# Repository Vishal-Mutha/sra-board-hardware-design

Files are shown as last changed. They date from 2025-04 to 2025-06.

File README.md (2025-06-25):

<!-- PROJECT LOGO -->
[][stars-url]
[][forks-url]
[][issues-url]
[][license-url]

<br/>

<p align="center">
  <a href="https://github.com/SRA-VJTI/sraboard-hardware-design">
    
  </a>

  <h3 align="center">SRA Development Board</h3>
  <p align="center">
    ESP32-based Development Board
    <br />
    <a href="https://github.com/SRA-VJTI/sra-board-hardware-design/tree/master/sra_dev_board_2025">KiCAD</a>
    ·
    <a href="https://github.com/Vishal-Mutha/sra-board-hardware-design/tree/master/gerbers">Gerber</a>
    ·
    <a href="https://github.com/Vishal-Mutha/sra-board-hardware-design/blob/master/documentation/images/board_images/front.png">Images</a>
    ·
    <a href="https://a360.co/3c1Rjyv">3D Model</a>
  </p>

# SRA Board 2025

The SRA board is a development board based on ESP32 with on-board peripherals like programmable LEDs, switches, sensor ports for Line Sensor Array and MPU-6050, protection circuit for over-current and reverse voltage and motor drivers.

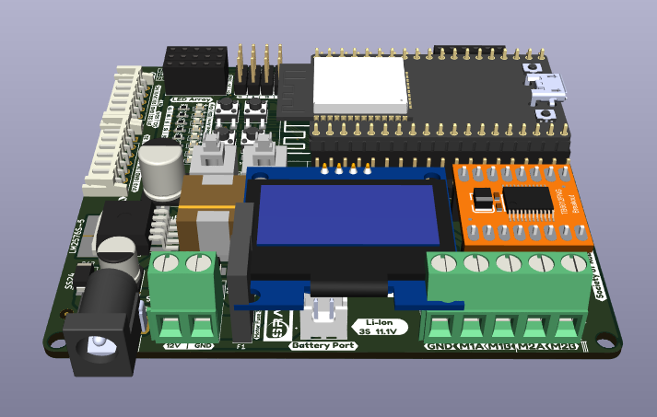
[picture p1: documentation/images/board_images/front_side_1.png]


## Table of Contents
- [SRA Board 2025](#sra-board-2025)
  - [Table of Contents](#table-of-contents)
  - [Board Images](#board-images)
  - [About the Project](#about-the-project)
  - [Getting Started with a Development Board](#getting-started-with-a-development-board)
  - [Notable problems in the previous SRA Boards](#notable-problems-in-the-previous-sra-boards)
  - [Notable problems in the current SRA Board](#notable-problems-in-the-current-sra-board)
  - [3D Models](#3d-models)
  - [Milestones](#milestones)
  - [Contributors](#contributors)
  - [Acknowledgements and Resources](#acknowledgements-and-resources)
  - [License](#license)

## Board Images
- **Frontside**
<p align="center">
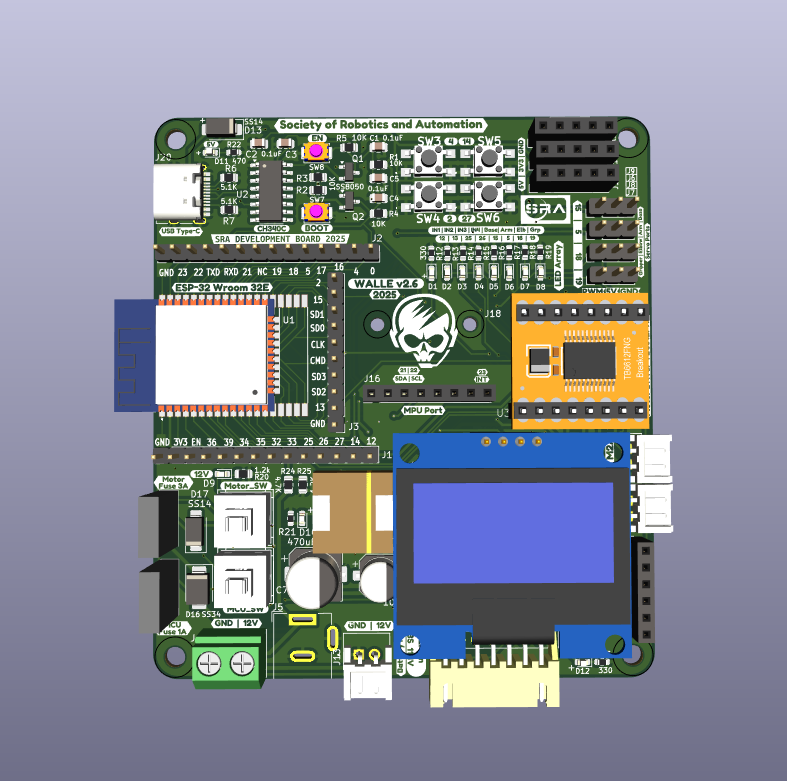
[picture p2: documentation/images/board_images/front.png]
  
</p>

- **Backside**
<p align="center">
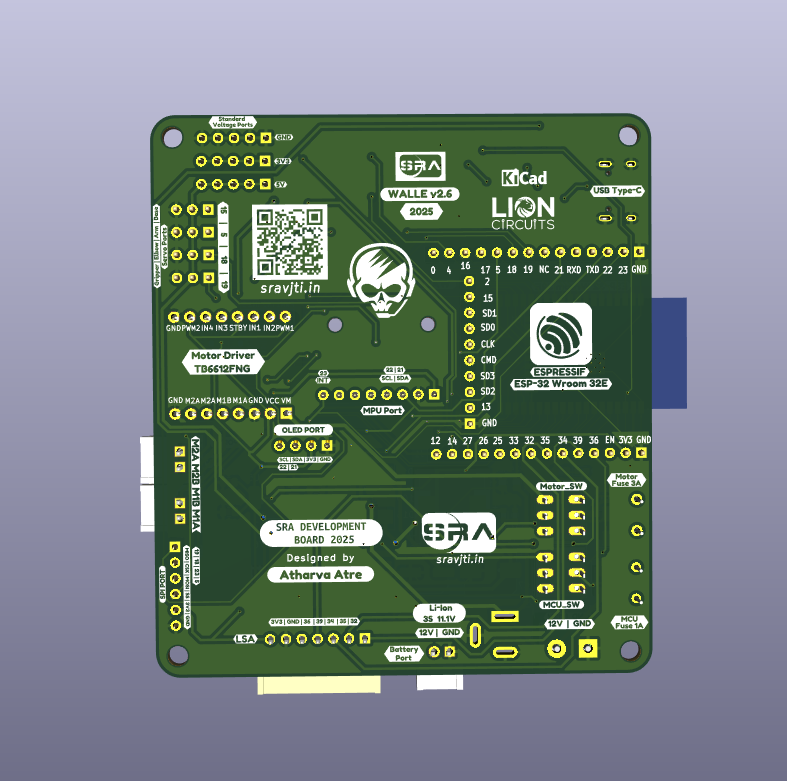
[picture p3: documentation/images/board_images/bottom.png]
  
</p>

## About the Project

- This development board is used for the [Wall-E](https://github.com/SRA-VJTI/Wall-E) and [MARIO](https://github.com/SRA-VJTI/MARIO) workshops conducted by [SRA](https://github.com/SRA-VJTI).
- Designed using KiCAD. The schematic and board files are [here](https://github.com/AtharvaAtre/SRA-Board/tree/master/sra_dev_board_2025).
- Resources for [previous work](https://github.com/SRA-VJTI/sra-board-hardware-design/tree/v2.2).  For more details of the SRA board 2020, checkout this [link](https://github.com/SRA-VJTI/sra-board-hardware-design/releases/tag/v2.4).
- The SRA board 2023 images can be found [here](https://github.com/SRA-VJTI/sra-board-hardware-design/tree/v2.4/documentation/images).
- Older versions of the board and miscellaneous designs can be found [here](https://github.com/SRA-VJTI/PCB-Schematics-and-Layouts).

## Getting Started with a Development Board

<p align="center">
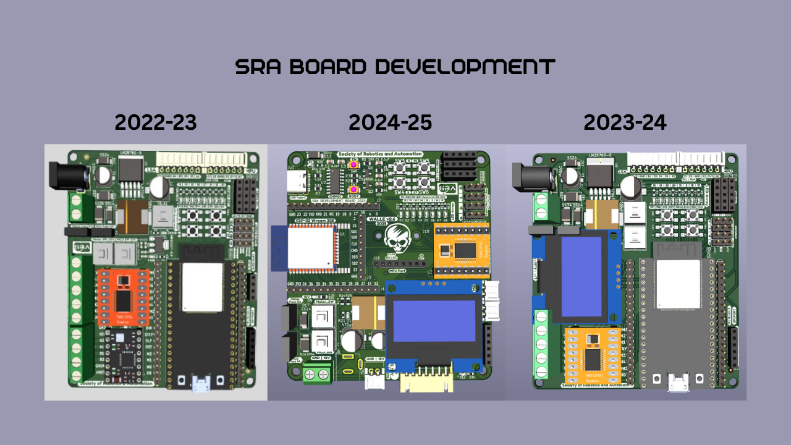
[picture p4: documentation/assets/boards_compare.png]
  
</p>

In general, every development board has the following basic features:

- ### Power Supply Unit
  - Microcontrollers (MCUs) usually run on 3.3V or 5V logic supply voltage while input to a development board is normally 12V for motor and driving/controlling peripheral devices.
  - So, in order to have a single input source, a *power* section which inter converts this 12V to standard levels like 5V & 3.3V for MCU and sensors is present.This is achieved using a step-down [buck regulator](https://www.youtube.com/watch?v=m8rK9gU30v4).
  - Buck Regulator IC [LM2576-S-5](./datasheets/lm2576_buck_regulator.pdf) is used for stepping down the voltage from 12V to 5V DC. This 5V is further regulated to 3.3V using LDO IC [AMS1117-3.3](./datasheets/ams1117_ldo.pdf).
  - The previous edition of the SRA board (2023) also used a similar buck regulator setup.
  - The older editions of the SRA board used the LM7805 linear voltage regulator, for stepping down from 12V to 5V; this powered the ESP32. Further, this 5V was converted to 3.3V using the LD33 linear voltage regulator, used by the sensor port.

- ### Motor Driver
    - Motors usually run on 12V and MCU output is generally 5V/3.3V. So, an external motor driver circuitry is required to control motors according to the MCU input.
    - The current and previous editions of SRA board use the [TB6612FNG](./datasheets/TB6612FNG_motor_driver.pdf) Motor Driver, which is a MOS-based H-Bridge motor driver.
    - The older editions of SRA Board used the L298N IC for motor-control, which is a BJT-based H-Bridge motor driver.

- ### Sensor Port
    - According to the external sensor types, usually development boards have onboard sensor ports where the sensors can be connected easily. [LSA - Line Sensor Array]() and [MPU- Motion Processing Unit]() have on-board connection ports.
    - The current edition uses easily available and efficient [JST XH connectors](https://en.wikipedia.org/wiki/JST_connector).
    - Previous versions used bulky [FRC connectors](https://www.sunrom.com/c/frc-idc-flat-cable-box-header#:~:text=FRC%20(Flat%20Ribon%20Cable)%20are,from%206%20to%2064%20pins.)

- ### Protection against [Reverse Voltage](https://www.google.com/url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)
    - The SRA Boards use diodes for reverse voltage protection in the power-line.
    - 12V Motor line and power regulated line have been separated with [SS34](./datasheets/ss34_3A_schottky_diode.pdf) and [SS24](./datasheets/ss24_2A_schottky_diode.pdf) schottky diodes respectively.

- ### Protection against [Over Current](https://www.baypower.com/blog/what-is-overcurrent-protection/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,of%20a%20piece%20of%20equipment.)
    - Earlier, for the overcurrent protection of MCU and motor driver circuit, bulky glass fuses of 300mA and 3A were used respectively. After breakdown, they used to be replaced.
    - In the recent versions of the board, these were replaced with compact, PTC Resettable Fuses.
    - On 12V line - [RXEF160](./datasheets/RUEF160_3,2A_trip_ptc_fuse.pdf) : 1.6A hold current; 3.2A trip current Fuse was used.
    - On 5V line - [RXEF160](./datasheets/RXEF050_1A_trip_ptc_fuse.pdf) : 0.5A hold current; 1A trip current Fuse was used.
- ### Programmable Switches and LEDs
    - Every development board should have some programmable switches and LEDs for testing, control and debugging purposes.
    - The current editions has an array of 8 programmable LEDs and switches.
    - The previous edition had a pair of programmable switches and programmable LEDs each.

- ### Power Switch
    - All versions have a power switch for the motor driver, using which power supply to the motor driver can be toggled. Similarly, there was a switch for the ESP32 MCU.

> Now that we covered basics of development boards, let us talk about the changes made in the new design. 

## Major Changes IN SRA Board Over the years from 2021-2025
| Feature  |  SRA Board 2021  | SRA Board 2022 | SRA Board 2023 | SRA Board 2024 | SRA Board 2025 |
|:----:|:---:| :-----: | :-----: | :-----: | :-----: |
|12V to 5V| LM2596 Buck Convertor | LM2596 Buck Converter | LM2576-S Buck Converter | LM2576-S Buck Converter | LM2576-S Buck Converter |
|Reverse Voltage Protection| P-MOSFET | Diodes | Diodes | Diodes | Diodes |
|Line Sensing Arrays (LSA)| Photodiodes| Photodiodes| IR Sensors| IR Sensors | IR Sensors |
|Number of LSA Sensors| 4| 4| 5| 5 | 5 |
|Motor Driver| TB6612FNG| TB6612FNG | TB6612FNG | TB6612FNG | TB6612FNG |
|Stepper Motor Driver| - | - | A4988 | - | - |
|No. of DC Motor Channels|4|4|2|2|2|
|No. of Stepper Motor Channels|0|0|1|1|0|
|No. of Switches|4|4|4|2|2|
|No. of LEDs|8|8|8|8|8|
|Over Current Protection| Bulky Glass Fuses | PTC Resettable Fuses | PTC Resettable Fuses| PTC Resettable Fuses | PTC Resettable Fuses |
|Sensor Port Connectors| JST (Japan Solderless Terminal) Connectors | JST (Japan Solderless Terminal) Connectors | JST Connectors | JST Connectors | JST Connectors |
|Component Type and Board Size| THT (Through Hole), Big | SMD(Surface Mount Device), Smaller | SMD(Surface Mount Device), Smaller| SMD(Surface Mount Device), Smaller | SMD(Surface Mount Device), Smaller |
|ESP32 Module| Not Integrated | Not Integrated | Not Integrated | Not Integrated | Mounted and Soldered to PCB |
|Flashing Port| Micro USB | Micro USB | Micro USB | Micro USB | Type-C |

- ### **Compatiblity of SRA Board with Battery [3- 3.3V 2500mAh Batteries](https://robu.in/product/bak-nmc-18650-2500mah-8c-lithium-ion-battery/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)**
    - This years SRA Board(2023-24) is compatible with batteries which have an external **[BMS(Battery Management System)](https://robu.in/product/3s-10a-12v-18650-lithium-battery-charger-board-protection-module/)**.
    - The BMS helps in maintaining an optimal voltage and disconnects itself when battery voltage drops below a significant voltage.
    - ALso the BMS helps in equal charging and discharging of 3 cells being used as a battery unit and thus helping in increasing the life/health of the battery.
    - ### **7805 (5V linear regulator) to [LM2576/96 Buck Convertor](https://www.youtube.com/watch?v=m8rK9gU30v4)**
    - The greater efficiency, output current and reliability of LM2576/96 were the reasons for this change.
    - The efficiency of LM2576 is up to 92% which is significantly better than 7805. The LM2576 can provide current up to 3A, so  the MARIO workshop manipulator can now be run using onboard regulator.
- ### **LD33 (3.3V) to [AMS1117](http://www.advanced-monolithic.com/pdf/ams1117.pdf)**:
    - The older editions used the LD33 IC to step down from 5V to 3.3V; several discussions resulted in the shift to more compact, reliable AMS1117-3.3(SOT-23) linear voltage regulator. (_AMS1117 is also used on-board on the ESP32-DevKitC V4 module_)

- ### **Reverse voltage protection: Diodes to P-MOSFET**
    - Diodes in series to the power line are inefficient as compare to a P-MOSFET. Dut to the usage of high-rated motors, it was difficult to manage the diode size and the current rating. (_As the current rating of diode increases, its size also increases._)So, the previous version uses the P-MOSFET instead of a diode, which is more efficient and can handle more current.
    - In the current edition, SMD diodes are used, hence rating and size is no longer an issue.

- ### **Component Type and Board Size**:
    - In the previous and older editions, THT or PTH(Plated through hole) components were used, which take up a lot of space and their size increases with increasing rating.
    - In the current edition, the component layout is changed,stepper motor driver is removed and the board is made battery compatible necessary changes for the same where done.
    - Current Board Dimensions: **81mm x 92.68mm**

- ### **L298N to [TB6612FNG](https://dronebotworkshop.com/tb6612fng-h-bridge/)**
    - L298N is a BJT-based H-bridge motor driver but it is less efficient as compared to the new MOS-based TB6612FNG.
    - The detailed comparison is shown below. As you can see the efficiency of TB6612FNG can reach up to 91-95% which is significantly higher than the 40-70% efficiency of L298N.
    - The only drawback of TB6612FNG is the less continuous current which is equal to 1.2A.
    
    <p align="center">
        
    </p>
- ### **Stepper Motor Driver Port ([A4988](https://www.tme.eu/Document/25459777e672c305e474897eef284f74/POLOLU-2128.pdf))**(Not present in 2023-24 and further)
    - In the Previous and older editions, there were two ports for TB6612FNG Motor Drivers but **it has been updated to one TB6612FNG and one A4988 Stepper Motor Driver in the current SRA Board (2023).** 
    - A4988 Stepper Motor Driver **a microstepping driver for controlling bipolar stepper motors** which has built-in translator for easy operation. This means that we can control the stepper motor with just 2 pins from our controller, or one for controlling the rotation direction and the other for controlling the steps.
    - The Driver provides five different step resolutions: full-step, haft-step, quarter-step, eight-step and sixteenth-step. Also, it has a potentiometer for adjusting the current output, over-temperature thermal shutdown and crossover-current protection.
    <p align="center">
        
    </p>

- ### **Moving back from the vintage Bar-graph LEDs to LED array and more switches**
    - The older edition used a pair of programmable switches and LEDs each.
    - Since the previous edition, the number of debuggable switches has been increased to 4.
    - The previous edition used an LED voltage bar-graph array of 10 LEDs which was very bulky.
    - In the current edition, 10 SMD LEDs arranged in an array out of which two are reserved for 5V and 3.3V voltage indication have been used.
    -  So there are 8 programmable LEDs on the board. These LEDs multiplexed with directional pins of the two motor drivers to save pins.
    -  Directional pins? >> Every motor driver channel has two directional pins IN1, IN2. If IN1 is high and IN2 is low then motors move in a clockwise direction and there are 4 channels on the board, so 4 * 2 = 8 directional pins are multiplexed with 8 programmable LEDs.
    -  With 8 LEDs in hand, debugging get easier. Some examples -
        1. According to the line sensor array (LSA) data, one can program 4 LEDs to turn on when the line sensor detects white  and turn off for black- line following debugging.
        2. If a motor is moving in a forward direction, the dedicated LEDs will be indicating IN1 is high and IN2 is low - motor control debugging.

## Notable problems in the previous SRA Boards
- ### **The Simultaneous Power Supply Issue**
    - ESP32 can be power using two ways - one via the USB port given on the ESP32 and two via providing a voltage on VIN pin.
    - In the SRA Board 2019, if simultaneous power (on both the above sources) was provided to the ESP32 then it won't work as there was no circuitry for handling such a condition.
    - The following disclaimer from the official ESP32 documentation made it essential to design some external circuit to handle this condition and accordingly pass only one signal to the ESP32 board.
    > *The power supply must be provided using one and only one of the above options.Otherwise, the board and/or the power supply source can be damaged.*
    - #### Solution
        - The solution for this issue was [Diode Auctioneering](http://doerry.org/norbert/papers/20190606-doerry-ashton-auctioneering-diodes.pdf).

        <p align="center">
            
        </p>

        - There is an inbuilt BAT760 diode on the USB line on ESP32. If different voltages are applied at Vusb and Vin, then the voltage with bigger magnitude will be given to LD1117 (LDO on ESP32); often the voltage will be the same on Vin and Vusb i.e 5V.
        - But, the usage of the SS14 (currently, 1N5417 in previous edition) diode on the Vin path, which has more **Vf** (forward voltage) than the BAT760, will create a voltage indifference and in a simultaneous power supply condition, USB will be selected as its voltage will be more than Vin.

## Notable problems in the previous SRA Board 
- ### **The High Frequency RF noise Issue**
    - Currently 300rpm rated BO motors were ultilised for application. These are brushed DC motors functioning currently on 12v working on PWM concept.
    - These BO motors drain a lot of current during operation. **90 - 100 mA** - during *normal operation*.
    But they drain about **600 - 700 mA** current - during *momentary or forced stalling*. Momentary stalling happens by itself.
    - For self balancing operation - the MCU communicates with MPU6050 for the current orientational readings and accordingly gives commands to the motor driver and thus the motors.
    - When this PWM goes over 50% duty cycle, the error in MPU readings become large and the motor rotate with full speed, thus not self-balancing the setup.
    - The following inspections were carried out os far so solve this issue.

    - #### Inspections
        - The static noise or low-frequecy noise generated by BO Motors was eliminated by soldering a 0.1uF ceramic capacitor across its terminals.
        - Initially, the longer length of the I2C line route + cable from the MPU6050 to the ESP32 was suspected to be the main culprt. However, the MPU was checked for I2C packet drop, which when observed under the a DSO, seemed pretty fine. While reading the Motion data, both the SDA and SCLK lines go high.
        - The dynamic high-frequency noise wasnt getting eliminated which is produced to the brush action of brushed DC motors. Finally adding [**ferrite beads**](https://www.youtube.com/watch?v=O39inZIscOI) across the motor terminals and using twisted cable pairs to connect it to the board lessened the RF noise to an extent.
        - Although, the above solution only facililated in lessening the frequency of system going into error. Also, the duty cycle was forced to be under 50% for opltimal application.

    - #### Possible Solutions
        - View this issue [#14](https://github.com/SRA-VJTI/sra-board-hardware-design/issues/14) for more details and advancements on the suggested solutions.
        - The above error didnot occur when L298 motor driver was used with the same setup.
        - Using N20 geared motors which draw relatively less current did not throw an error.
        - MPU can be taken upwards on the board itself rather than keeping it below near the motors so that noise can be minimized.        
        - Task is to figure out an economical alternative considering it to be a hardware issue.

## 3D Models

1. The complete 3D model (.step) file of [SRA Board 2025](./3d_models/sra_board_model/sra_dev_board_2025.step)
2. The 3D models of motor driver, LEDs, ESP32 etc.: [3d models of other components](./3d_models/)

<!-- Milestone -->
## Milestones

- [x] Designing of the prototype board
- [x] Modular testing of the circuit
- [x] Testing of prototype board
- [x] Final version
- [x] Making the board Battery Compatible
- [ ] Resolving high frequency noise by BO Motors ( TB6612FNG )

<!-- CONTRIBUTORS -->
## Contributors

- [Atharva Atre](https://github.com/AtharvaAtre): *Designer*
- [Dhairya Shah](https://github.com/dhairyashah1): *Mentor*
- [Mahesh Tupe](https://github.com/Asc91): *Mentor*
<!-- ACKNOWLEDGEMENTS AND REFERENCES -->
## Acknowledgements and Resources

- Previous Edition: [SRA Board 2024](https://github.com/SRA-VJTI/sra-board-hardware-design/releases/tag/v2.5)
- [KiCAD Tutorials](https://www.youtube.com/playlist?list=PL3bNyZYHcRSUhUXUt51W6nKvxx2ORvUQB)
- [README Template](https://github.com/roshanlam/ReadMeTemplate) by [roshanlam](https://github.com/roshanlam)

## License

- Distributed under the [MIT License](https://github.com/SRA-VJTI/sraboard-hardware-design/blob/master/LICENSE).

[forks-shield]:https://img.shields.io/github/forks/SRA-VJTI/sra-board-hardware-design
[forks-url]: https://github.com/SRA-VJTI/sra-board-hardware-design/network/members

[stars-shield]: https://img.shields.io/github/stars/SRA-VJTI/sra-board-hardware-design
[stars-url]: https://github.com/SRA-VJTI/sra-board-hardware-design/stargazers

[issues-shield]: https://img.shields.io/github/issues/SRA-VJTI/sra-board-hardware-design
[issues-url]: https://github.com/SRA-VJTI/sra-board-hardware-design/issues

[license-shield]: https://img.shields.io/github/license/SRA-VJTI/sra-board-hardware-design
[license-url]: https://github.com/SRA-VJTI/sra-board-hardware-design/blob/master/LICENSE

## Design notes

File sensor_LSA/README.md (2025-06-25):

## LSA - Line Sensor Array

### Table of Contents
* [Overview](#overview)
* [Features](#features)
* [Components of LSA](#components-of-lsa)
* [Function of Components](#function-of-components)
	* [LED](#function-of-components)
	* [PhotoDiode](#function-of-components)
	* [IC LM324](#function-of-components)
	* [Resistors](#function-of-components)
* [Connections](#connections)
* [Working Principle](#working-principle)
* [Appplications](#applications)
* [Scope of Improvement](#scope-of-improvement)

### Overview
- The Line Sensor Array(LSA) is used to detect the white/black lined surface and it sends this data to the microcontroller ESP-32. Analyzing and processing the data received by the microcontroller ESP-32, the purpose of line following is achieved.

- Physical PCB
<p align="center">
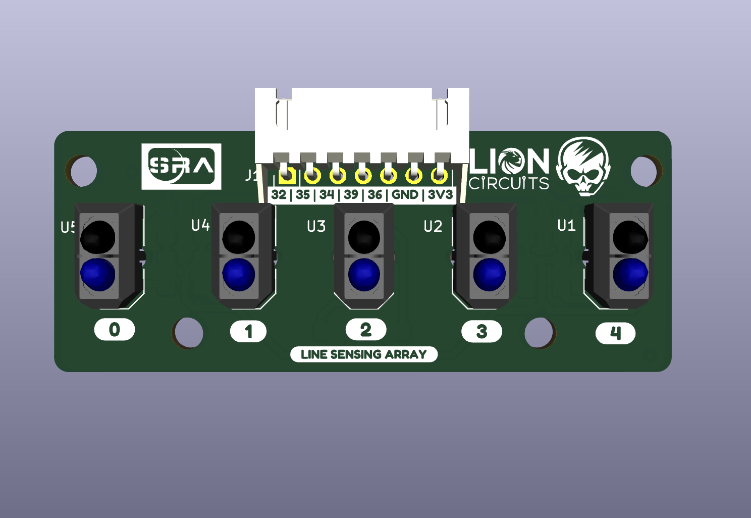
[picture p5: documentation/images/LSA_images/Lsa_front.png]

</p>

- PCB Backside
<p align="center">
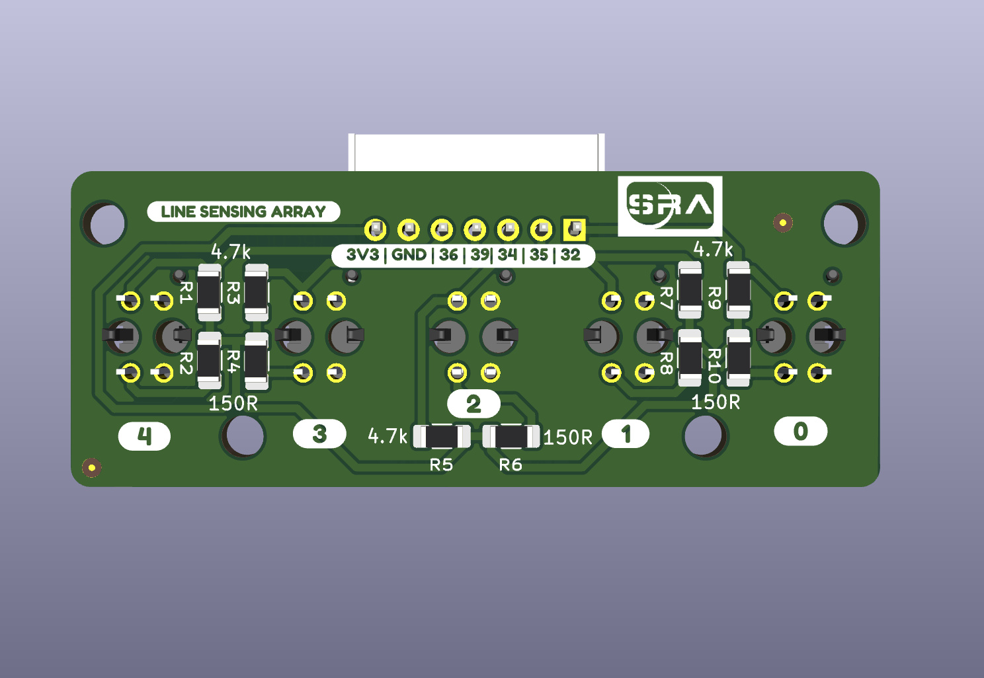
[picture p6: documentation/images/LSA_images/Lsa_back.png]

</p>

### Features
* Components used are readily available.
* Easy connections for output signals.
* Compact enough to fit into any project.
* Distinguished trace widths for Signal and Power Routes.

### Components of LSA
| Component | Description | Quantity |
| --- | --- | --- |
| Infrared Emmitter | Emits infrared light |  5 |
| PhotoTransistor  | Absorbs light |  5 |
| Resistors | Limit Current |  10 |
|JST Connector | Connect PCB with other circuits|1|

### Function of Components
- **Infrared Emmitter**
	- The specific Infrared Emmitter emit infrared light which is incident on the surface and some of it is absorbed by the surface. The voltage source for the Infrared Emmitter to emit is VCC.

- **PhotoTransistor**
	- Based upon the reflectivity coefficient of the surface( generally less than 1), the remaining light reflected from the surface is captured by the Photodiodes. Infrared Emmitter and complimentary phototransistor are used to efficiently detect the surface (white/black line). The amount of light received is directly proportional to the current generated by it. More the light, more the current, more the reading.

- **Resistors**
	- Now to limit the current and thus to protect the LEDs, PhotoDiodes current limiting resistors are used.

### Connections
To connect LSA with the SRA Board, connect the JST connector in the following way:
<p align="center">
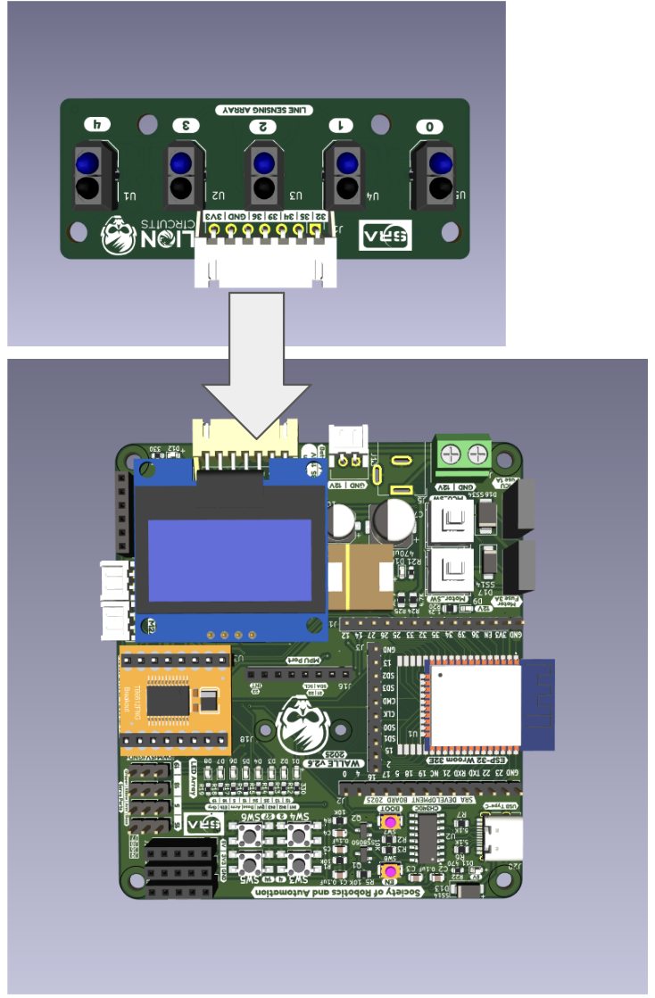
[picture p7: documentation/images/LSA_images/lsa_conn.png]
 
</p>

### Working Principle
- LSA works on the principle of reflectivity of light for different types of surfaces.
	- Black Surface -> HIGH absorptivity -> LESS reflectivity
	- White Surface -> LOW absorptivity -> HIGH reflectivity
- Demonstration
<p align="center">
 
</p>

### Applications
* Obstacle detection on a clear path.
* Line Following.
* Distinguish Colours on a path.

### Scope of Improvement
- LSA sometimes provides slightly inaccurate readings due to external light and conditions due to non uniformity of the colour of the path. Therefore, LSA has low accuracy. Hence LSA should be kept close to the ground.
- As of now only white and black surfaces are being mapped. Given accurate sensors and proper mapping we can map LSA for any range of RGB colours.

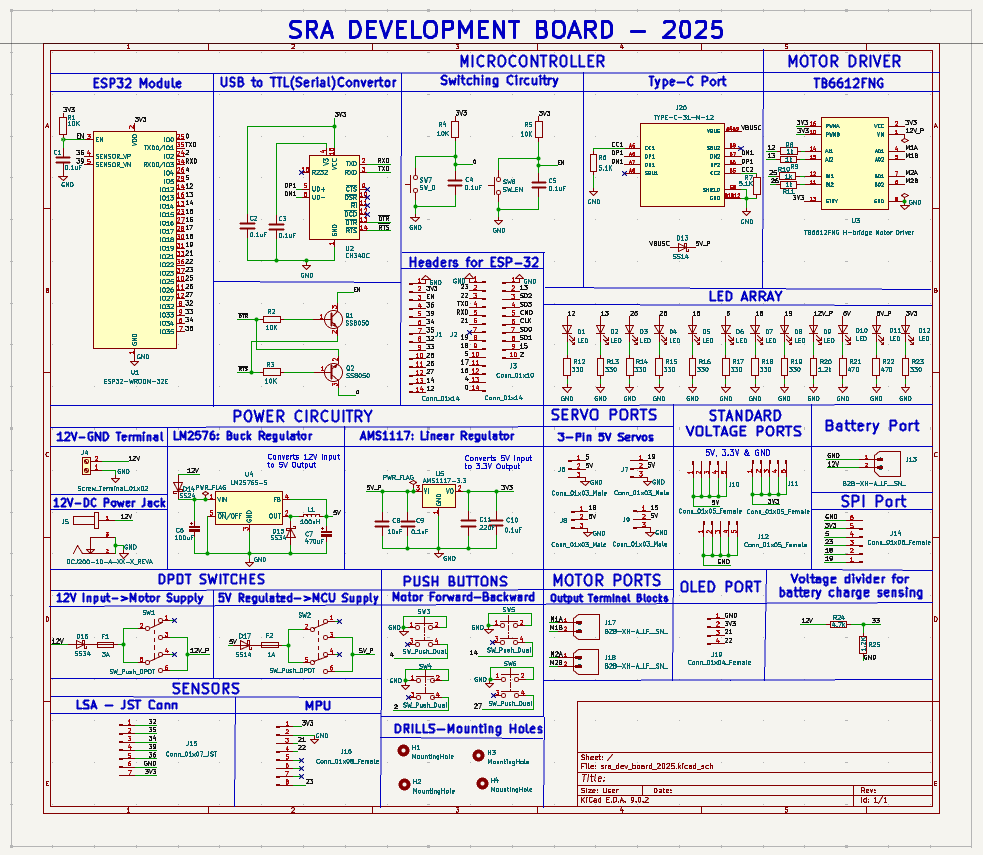
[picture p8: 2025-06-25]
documentation/images/board_images/schematic.png

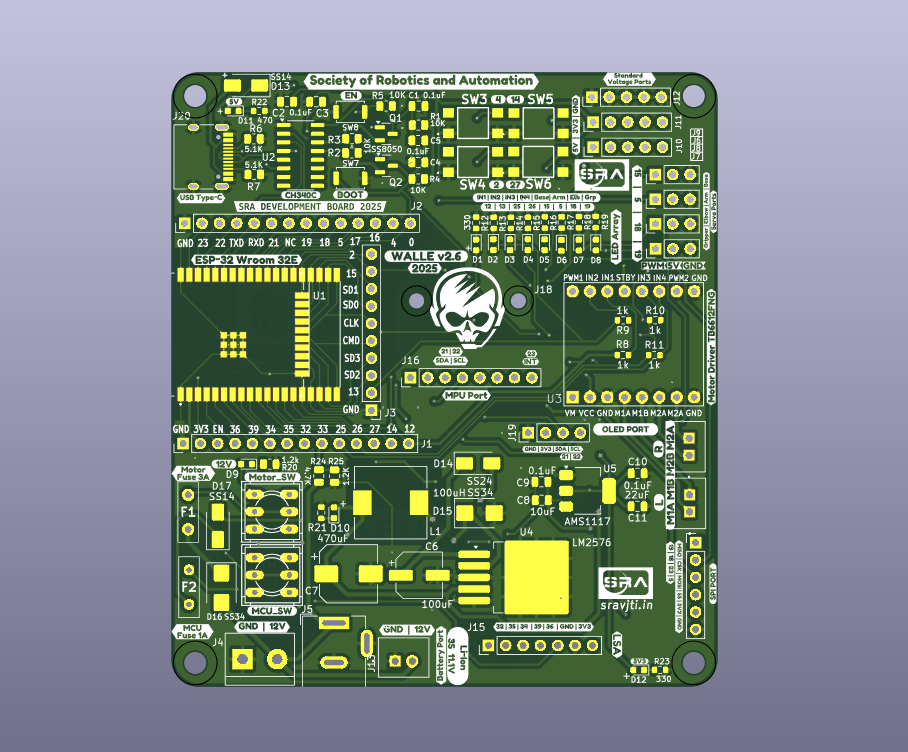
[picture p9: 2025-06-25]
documentation/images/board_images/front_silkscreen.png

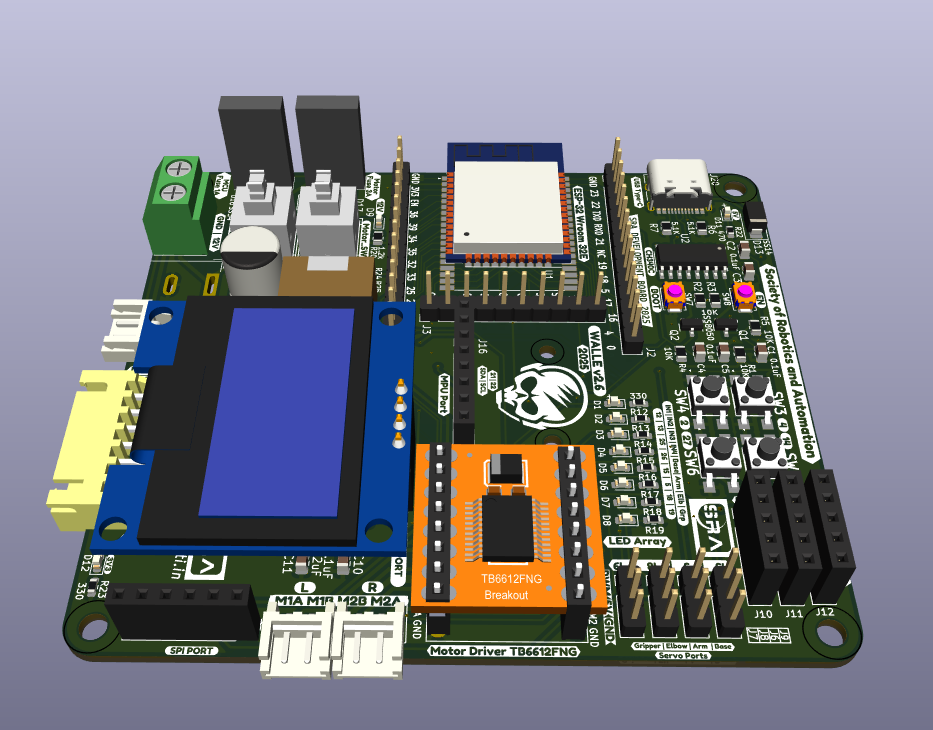
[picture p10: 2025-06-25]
documentation/images/board_images/front_view_1.png

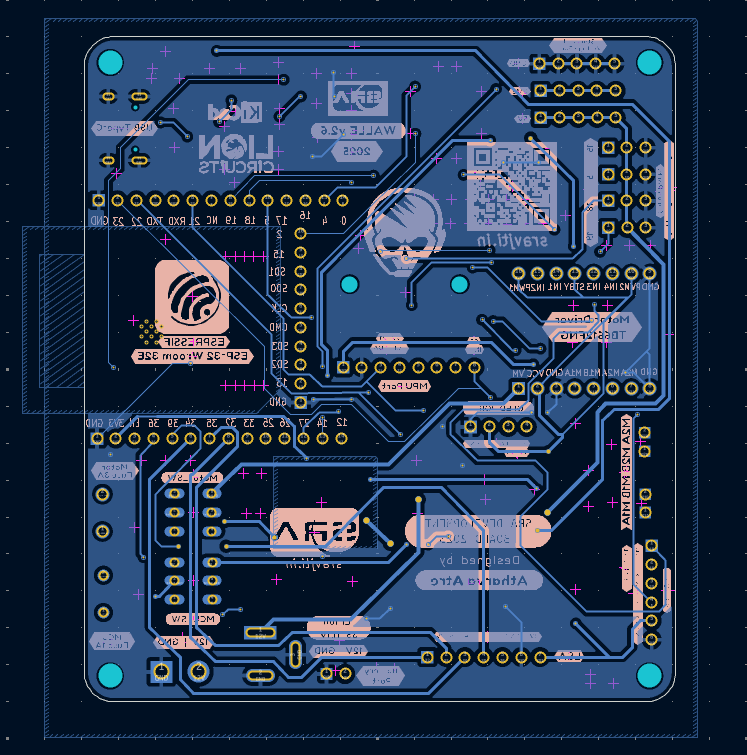
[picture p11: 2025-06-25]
documentation/images/board_images/bcu.png

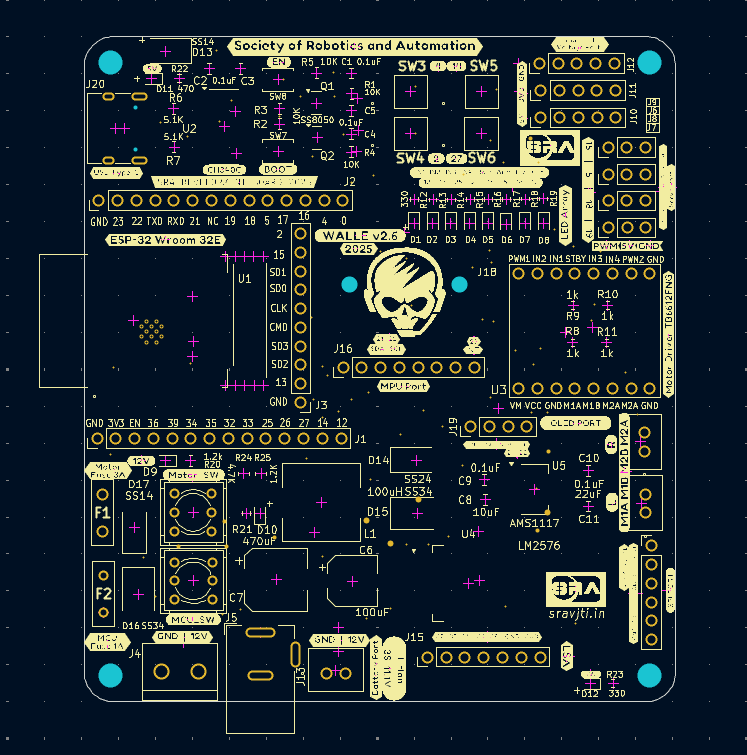
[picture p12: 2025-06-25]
documentation/images/board_images/front_silk_layer.png

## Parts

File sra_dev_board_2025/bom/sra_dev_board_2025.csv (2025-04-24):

Sr No. | Reference | Value | Footprint | Qty | Description
1 | C1,C2,C3,C4,C5,C9,C10 | 0.1uF | Capacitor_SMD:C_0805_2012Metric | 7 | Capacitor
2 | C6 | 100uF | Capacitor_SMD:CP_Elec_6.3x7.7 | 1 | Capacitor
3 | C7 | 470uF | Capacitor_SMD:CP_Elec_8x10 | 1 | Capacitor
4 | C8 | 10uF | Capacitor_SMD:C_0805_2012Metric | 1 | Capacitor
5 | C11 | 22uF | Capacitor_SMD:C_0805_2012Metric | 1 | Capacitor
6 | D1,D2,D3,D4,D5,D6,D7,D8,D9,D10,D11,D12 | LED | LED_SMD:LED_0603_1608Metric | 12 | LED
7 | D13,D17 | SS14 | Diode_SMD:D_SMA | 2 | Schotky Diode
8 | D14 | SS24 | Diode_SMD:D_SMA | 1 | Schotky Diode
9 | D15,D16 | SS34 | Diode_SMD:D_SMB | 2 | Schotky Diode
10 | F1 | 3A | PTC Fuse:3A RUEF160 | 1 | Fuse
11 | F2 | 1A | PTC Fuse:3A RUEF160 | 1 | Fuse
12 | J1,J2 | Conn_01x14 | Connector_PinHeader_2.54mm:PinHeader_1x14_P2.54mm_Vertical | 2 | Male Header
13 | J3 | Conn_01x10 | Connector_PinHeader_2.54mm:PinHeader_1x10_P2.54mm_Vertical | 1 | Male Header
14 | J4 | Screw_Terminal_01x02 | TerminalBlock:TerminalBlock_bornier-2_P5.08mm | 1 | 2 Pin Screw Terminal
15 | J5 | DCJ200-10-A-XX-X_REVA | Connector_BarrelJack:BarrelJack_Wuerth_6941xx301002 | 1 | DC Jack
16 | J6,J7,J8,J9 | Conn_01x03_Male | Connector_PinHeader_2.54mm:PinHeader_1x03_P2.54mm_Vertical | 4 | Male Header
17 | J10,J11,J12 | Conn_01x05_Female | Connector_PinHeader_2.54mm:PinHeader_1x05_P2.54mm_Vertical | 3 | Female Header
18 | J13,J17,J18 | B2B-XH-A_LF__SN_ | JST Connector:2 Pin JST Connector | 3 | JST Connector 2 Pin
19 | J14 | Conn_01x06_Female | Connector_PinHeader_2.54mm:PinHeader_1x06_P2.54mm_Vertical | 1 | Female Header
20 | J15 | Conn_01x07_JST | Connector_PinHeader_2.54mm:PinHeader_1x07_P2.54mm_Vertical | 1 | JST Connector 7 Pin
21 | J16 | Conn_01x08_Female | Connector_PinHeader_2.54mm:PinHeader_1x08_P2.54mm_Vertical | 1 | Female Header
22 | J19 | Conn_01x04_Female | Connector_PinHeader_2.54mm:PinHeader_1x04_P2.54mm_Vertical | 1 | Female Header
23 | J20 | TYPE-C-31-M-12 | Connector_USB:USB_C_Receptacle_HRO_TYPE-C-31-M-12 | 1 | Type-C Connector
24 | L1 | 100uH | Inductor_SMD:L_10.4x10.4_H4.8 | 1 | Inductor
25 | Q1,Q2 | SS8050 | Package_TO_SOT_SMD:SOT-23 | 2 | Trannsistor
26 | R1,R2,R3,R4,R5 | 10K | Resistor_SMD:R_0805_2012Metric | 5 | Resistor
27 | R6,R7 | 5.1K | Resistor_SMD:R_0805_2012Metric | 2 | Resistor
28 | R8,R9,R10,R11 | 1k | Resistor_SMD:R_0603_1608Metric | 4 | Resistor
29 | R12,R13,R14,R15,R16,R17,R18,R19,R23 | 330 | Resistor_SMD:R_0603_1608Metric | 9 | Resistor
30 | R20,R25 | 1.2k | Resistor_SMD:R_0805_2012Metric | 2 | Resistor
31 | R21,R22 | 470 | Resistor_SMD:R_0603_1608Metric | 2 | Resistor
32 | R24 | 4.7k | Resistor_SMD:R_0805_2012Metric | 1 | Resistor
33 | SW1,SW2 | SW_Push_DPDT | Switches:dpdt_sw_2x03_tht | 2 | 6 Pin DPDT Switch
34 | SW3,SW4,SW5,SW6 | SW_Push_Dual | Switches:spst_tactile_sw_2x02_smd | 4 | 4 Pin Tactile Switch
35 | SW7,SW8 | SW_0,SW_EN | Button_Switch_SMD:SW_Push_SPST_NO_Alps_SKRK | 2 | 2 Pin Tactile Switch
36 | U1 | ESP32-WROOM-32E | ESP-32:ESP32-WROOM-32E__4MB_HIGH_TEMP_ | 1 | ESP32 Wroom 32E
37 | U2 | CH340C | Package_SO:SOIC-16_3.9x9.9mm_P1.27mm | 1 | USB TTL Convertor
38 | U3 | TB6612FNG H-bridge Motor Driver | Motor Drivers:TB6612FNG | 1 | 2 1x8 Female Headers
39 | U4 | LM2576S-5 | Package_TO_SOT_SMD:TO-263-5_TabPin3 | 1 | Buck Convertor
40 | U5 | AMS1117-3.3 | Package_TO_SOT_SMD:SOT-223-3_TabPin2 | 1 | Linear Voltage regulator

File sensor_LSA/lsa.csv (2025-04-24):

Source: | /home/chinmay/Desktop/sra-board-hardware-design/sensors_2023/lsa/lsa/lsa.kicad_sch
Date: | Sun 11 Dec 2022 02:22:51 AM IST
Tool: | Eeschema 6.0.9-8da3e8f707~117~ubuntu22.04.1
Generator: | /usr/share/kicad/plugins/bom_csv_grouped_by_value_with_fp.py
Component Count: | 16
Ref | Qnty | Value | Cmp name | Footprint | Description | Vendor
J1, | 1 | Conn_01x07_Male | Conn_01x07_Male | Connector_PinHeader_2.54mm:PinHeader_1x07_P2.54mm_Vertical | Generic connector, single row, 01x07, script generated (kicad-library-utils/schlib/autogen/connector/)
R1, R3, R5, R7, R9, | 5 | 4.7k | R | Resistor_SMD:R_1206_3216Metric_Pad1.30x1.75mm_HandSolder | Resistor
R2, R4, R6, R8, R10, | 5 | 150R | R | Resistor_SMD:R_1206_3216Metric_Pad1.30x1.75mm_HandSolder | Resistor
U1, U2, U3, U4, U5, | 5 | TCRT5000 | TCRT5000 | TCRT5000:OPTO_TCRT5000

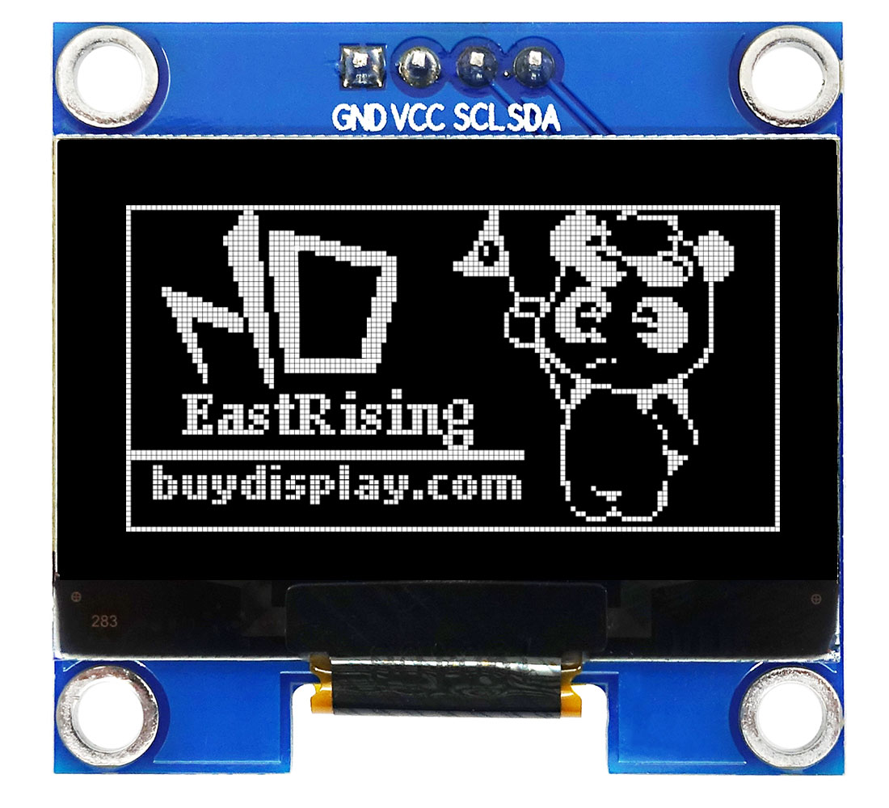
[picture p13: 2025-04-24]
sra_dev_board_2025/component_libraries/oled/I2C White 1.3 inch OLED Display Module 128x64 Arduino,Raspberry Pi.jpg

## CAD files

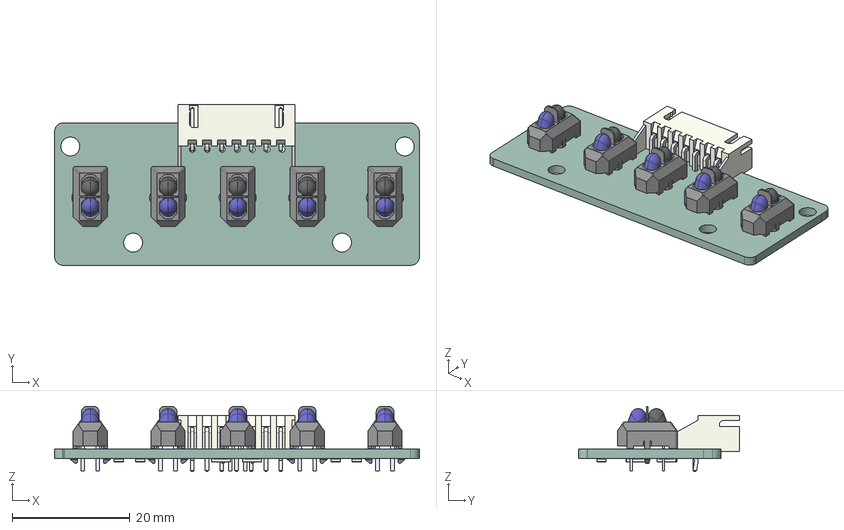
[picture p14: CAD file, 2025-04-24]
3d_models/lsa_model/lsa-2025.step
61.9 x 27.3 x 11.1 mm
JST_S7B_XH_A_1
TCRT5000 x 5
R_1206_3216Metric x 10
_autosave-lsa_PCB

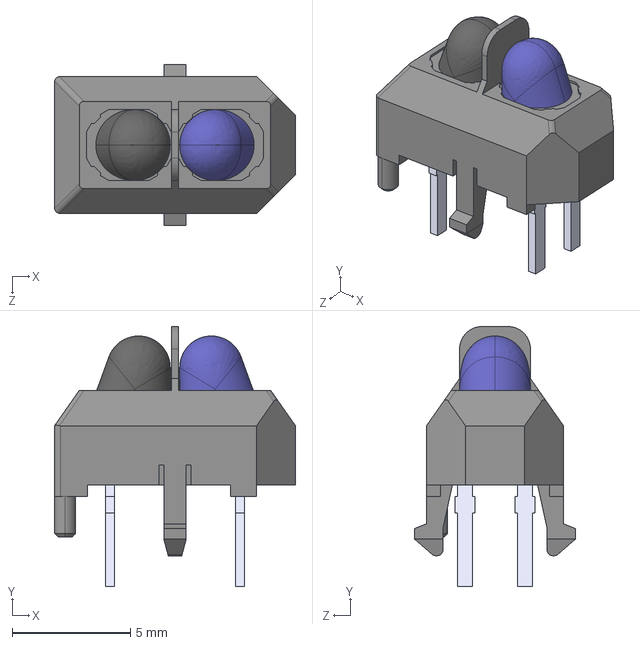
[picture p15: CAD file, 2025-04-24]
sensor_LSA/component_libraries/TCRT5000/TCRT5000.step
10.2 x 11.0 x 6.80 mm

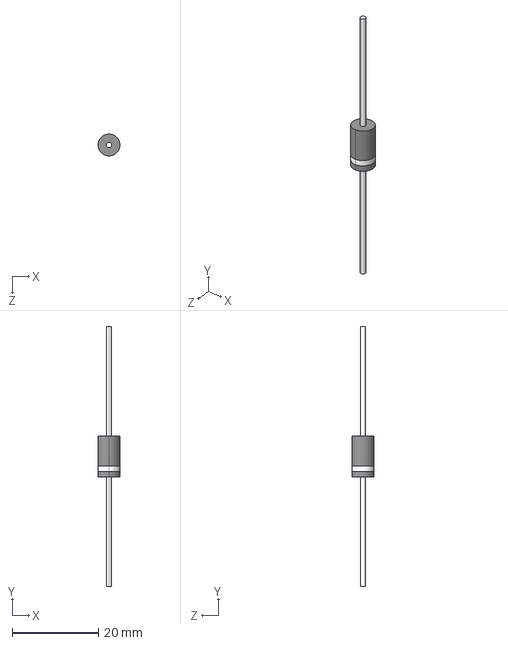
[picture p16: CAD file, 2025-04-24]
sra_dev_board_2025/component_libraries/diode/1N5822/1N5822.STEP
5.08 x 60.3 x 5.08 mm

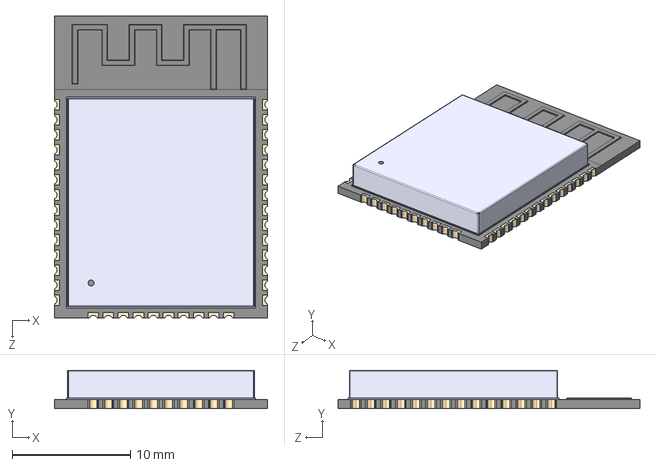
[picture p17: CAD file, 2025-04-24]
sra_dev_board_2025/component_libraries/ESP32-WROOM/ESP32-WROOM-32E__4MB_HIGH_TEMP_.step
18.0 x 3.25 x 25.5 mm

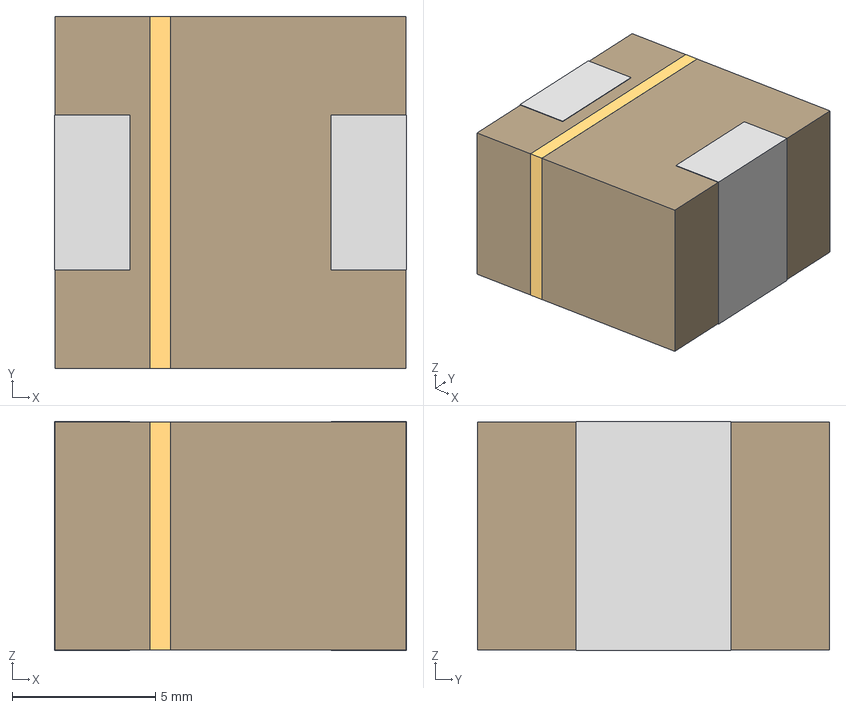
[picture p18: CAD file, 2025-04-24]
sra_dev_board_2025/component_libraries/inductor/CDRH127_inductor_smd.step
12.3 x 12.3 x 8.00 mm

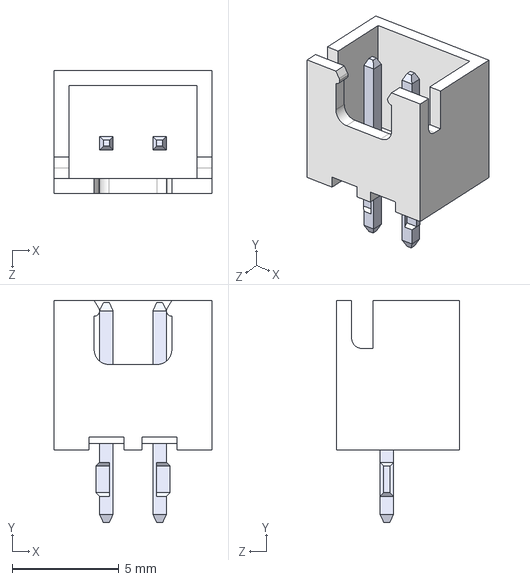
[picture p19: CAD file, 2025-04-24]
sra_dev_board_2025/component_libraries/JST Connector/2 Pin JST_Power&Motors/B2B-XH-A_LF__SN_.step
7.40 x 10.4 x 5.75 mm

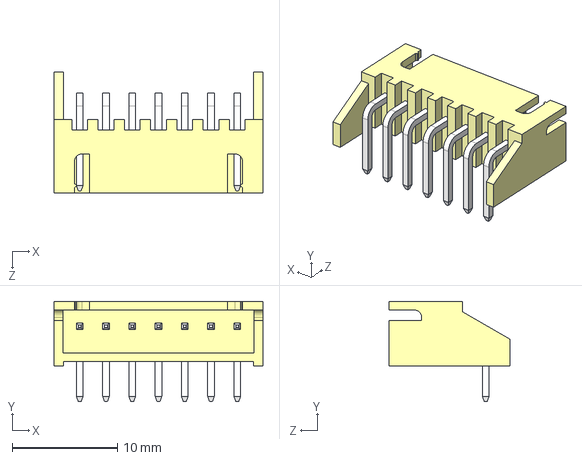
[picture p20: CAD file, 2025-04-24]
sra_dev_board_2025/component_libraries/JST Connector/7 Pin JST_LSA/S7B-XH-A_LF__SN_.step
19.9 x 9.55 x 11.5 mm

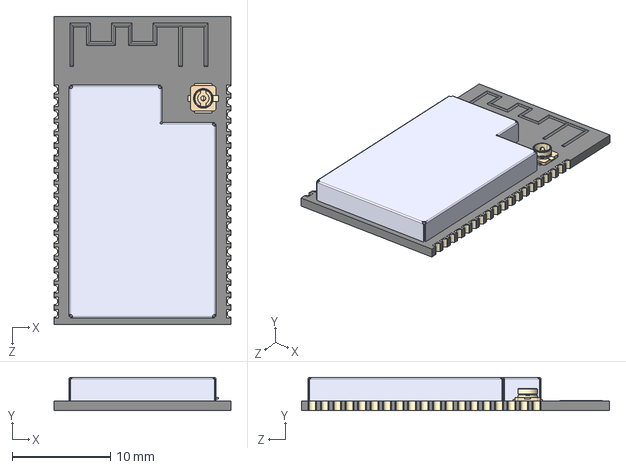
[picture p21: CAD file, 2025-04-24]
sra_dev_board_2025/component_libraries/MCU_ESP32/ESP32-WROVER.step
18.0 x 3.40 x 31.4 mm

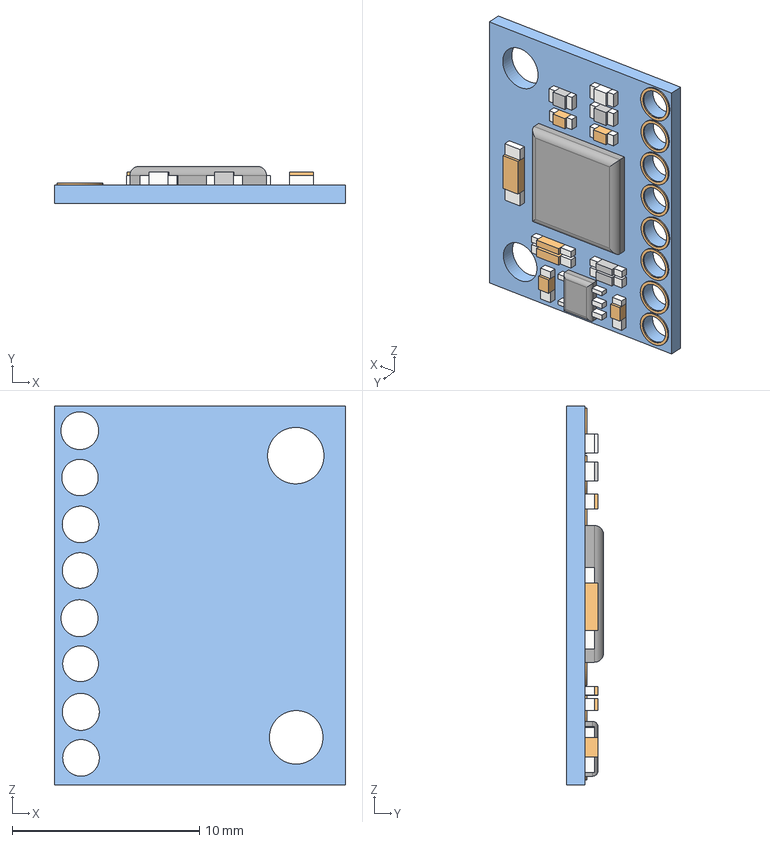
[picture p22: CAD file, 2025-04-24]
sra_dev_board_2025/component_libraries/MPU/MPU6050/MPU6050 v2.step
15.6 x 2.00 x 20.3 mm

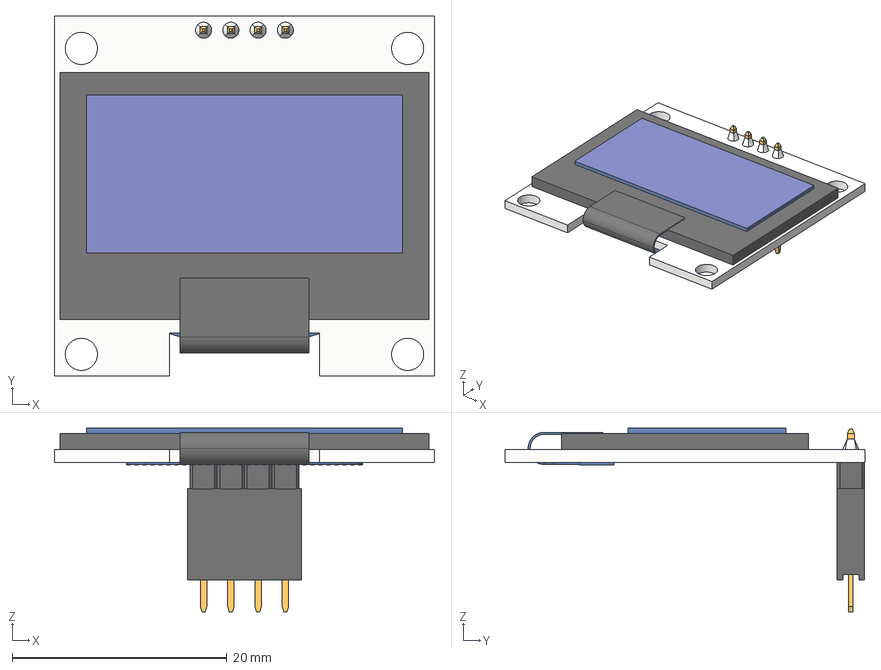
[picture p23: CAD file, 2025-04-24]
sra_dev_board_2025/component_libraries/oled/PCB v8.step
35.4 x 33.5 x 17.1 mm
Board
PIN HEADER MALE 2.54MM P4
LCD
FLEX FILM
4 lü Lehim
PIN HEADER FAMALE 2.54MM P4

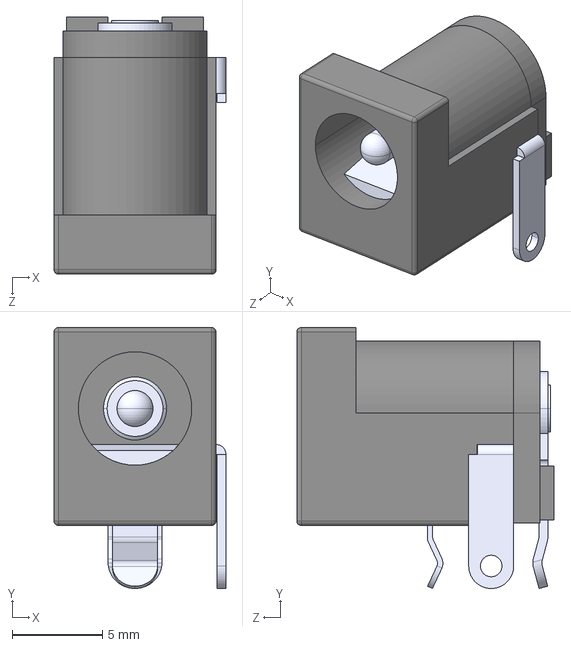
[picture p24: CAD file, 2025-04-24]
sra_dev_board_2025/component_libraries/power_jack/dc_power_jack.step
9.55 x 14.5 x 14.3 mm

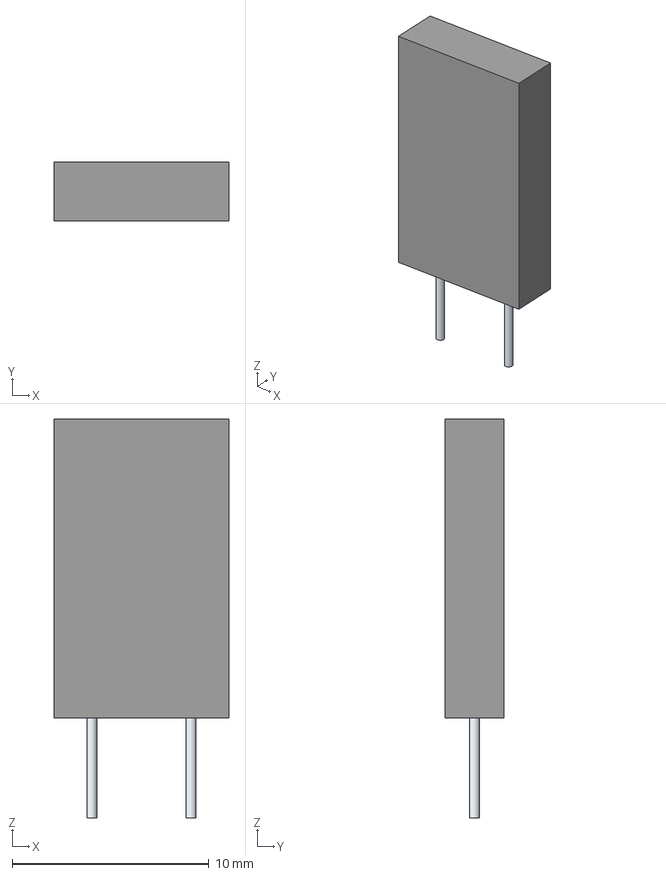
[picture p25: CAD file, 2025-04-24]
sra_dev_board_2025/component_libraries/ptc_fuse/RUEF150_3,2A_trip/RUEF160.stp
8.90 x 3.00 x 20.3 mm
Leads

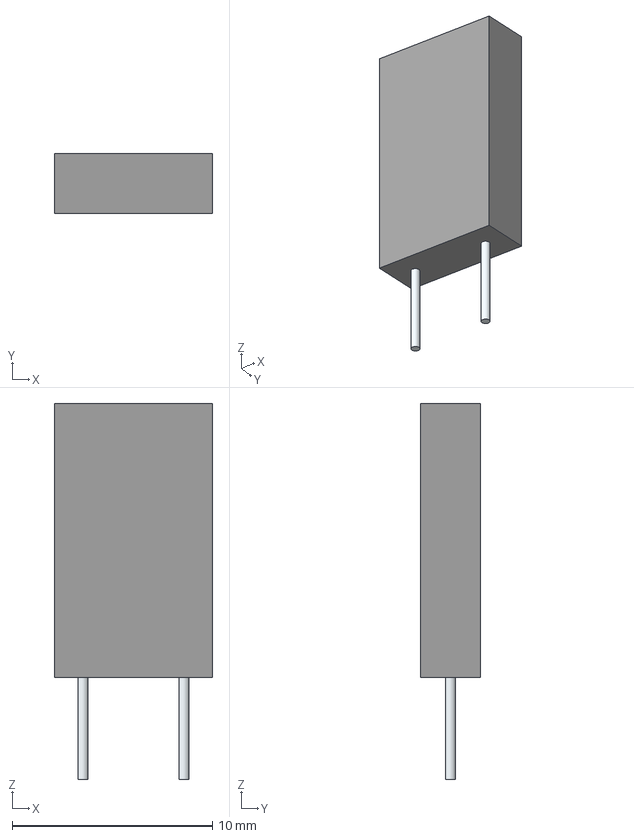
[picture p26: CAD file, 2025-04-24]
sra_dev_board_2025/component_libraries/ptc_fuse/RXEF050_1A_trip/RXEF050.stp
7.90 x 3.00 x 18.8 mm
Leads x 2

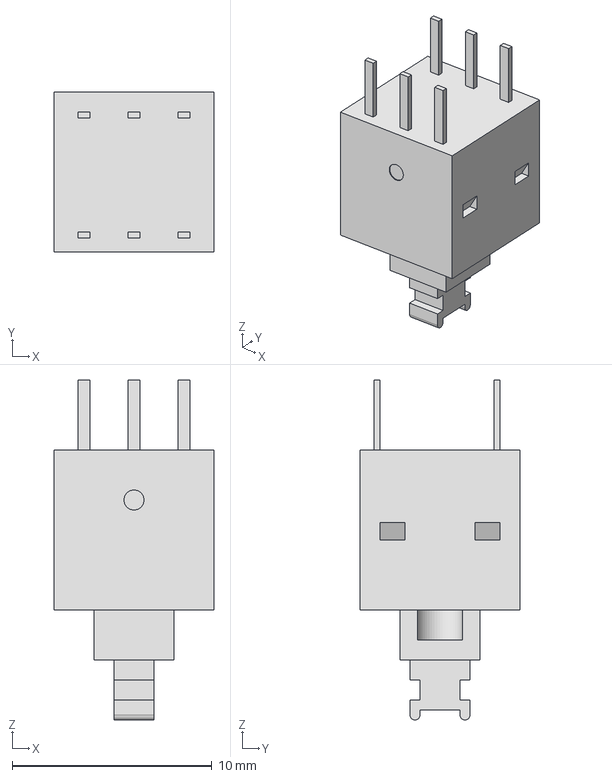
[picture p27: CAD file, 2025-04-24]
sra_dev_board_2025/component_libraries/switches/dpdt_tht/dpdt_sw_2x03_tht.STEP
8.00 x 8.00 x 17.0 mm

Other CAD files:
sra_dev_board_2025/component_libraries/switches/Esp-32 Switch/skrkaee010.stp
sra_dev_board_2025/component_libraries/switches/tactile_smd/spst_tactile_sw_2x02_smd.stp
sra_dev_board_2025/component_libraries/terminal_block/12V_1x02_tht.step
sra_dev_board_2025/component_libraries/inductor/CDRH104R_inductor_smd.stp
sra_dev_board_2025/component_libraries/oled/ER-OLEDM013-1-SPI-I2C.x_t
sra_dev_board_2025/component_libraries/oled/PCB v8.f3d
sra_dev_board_2025/component_libraries/ptc_fuse/RUEF150_3,2A_trip/RUEF160.stl
sra_dev_board_2025/component_libraries/ptc_fuse/RXEF050_1A_trip/RXEF050.stl

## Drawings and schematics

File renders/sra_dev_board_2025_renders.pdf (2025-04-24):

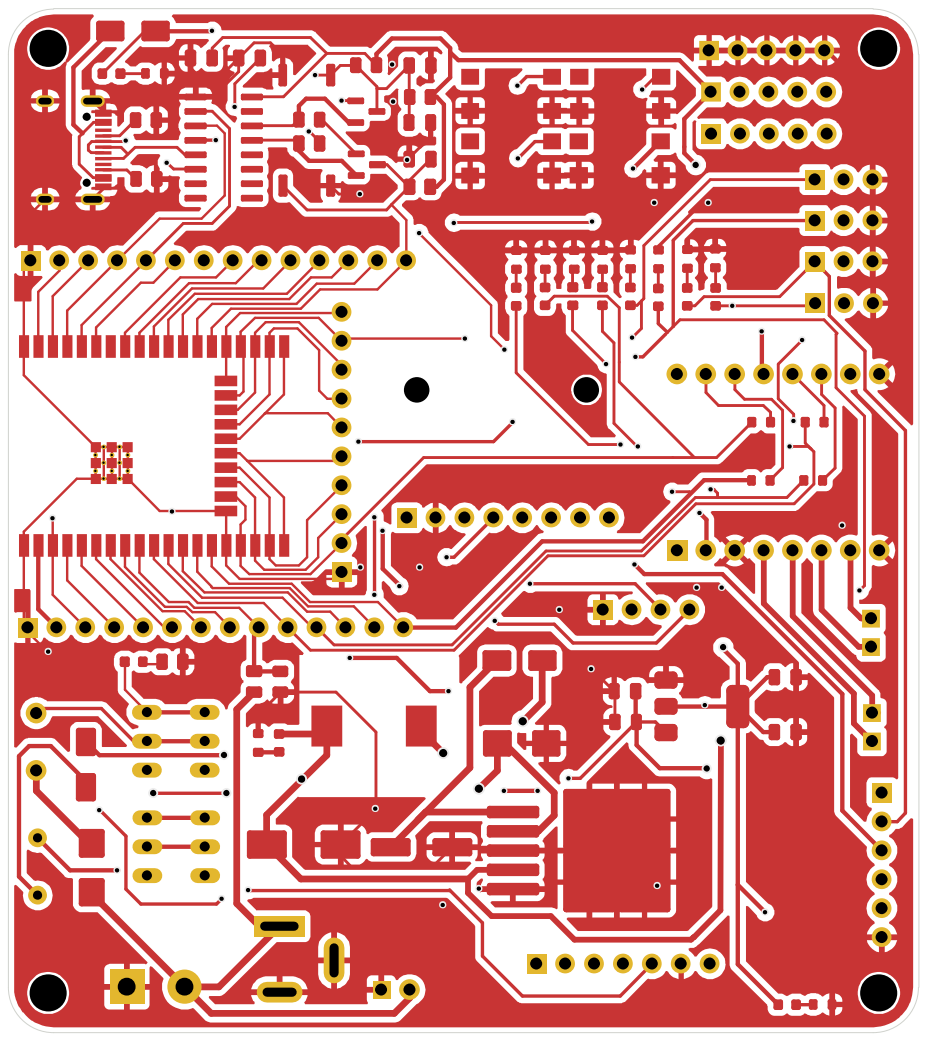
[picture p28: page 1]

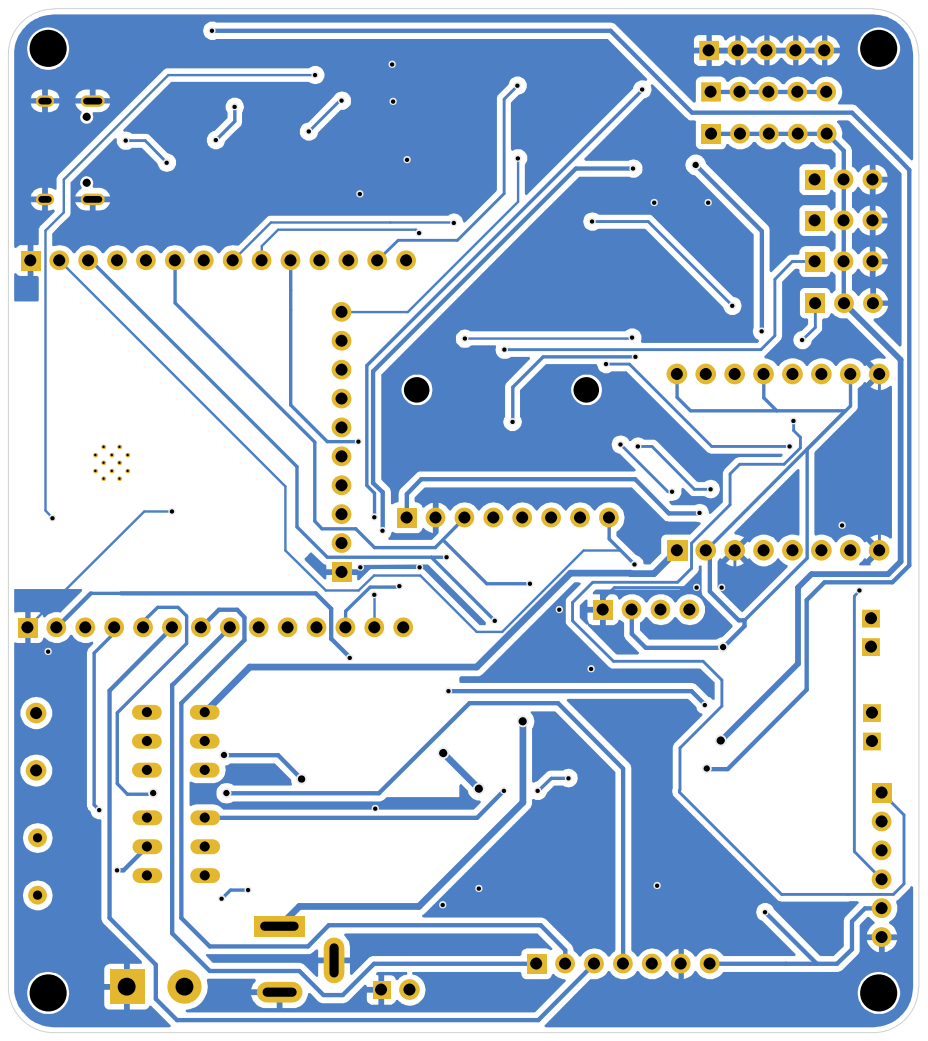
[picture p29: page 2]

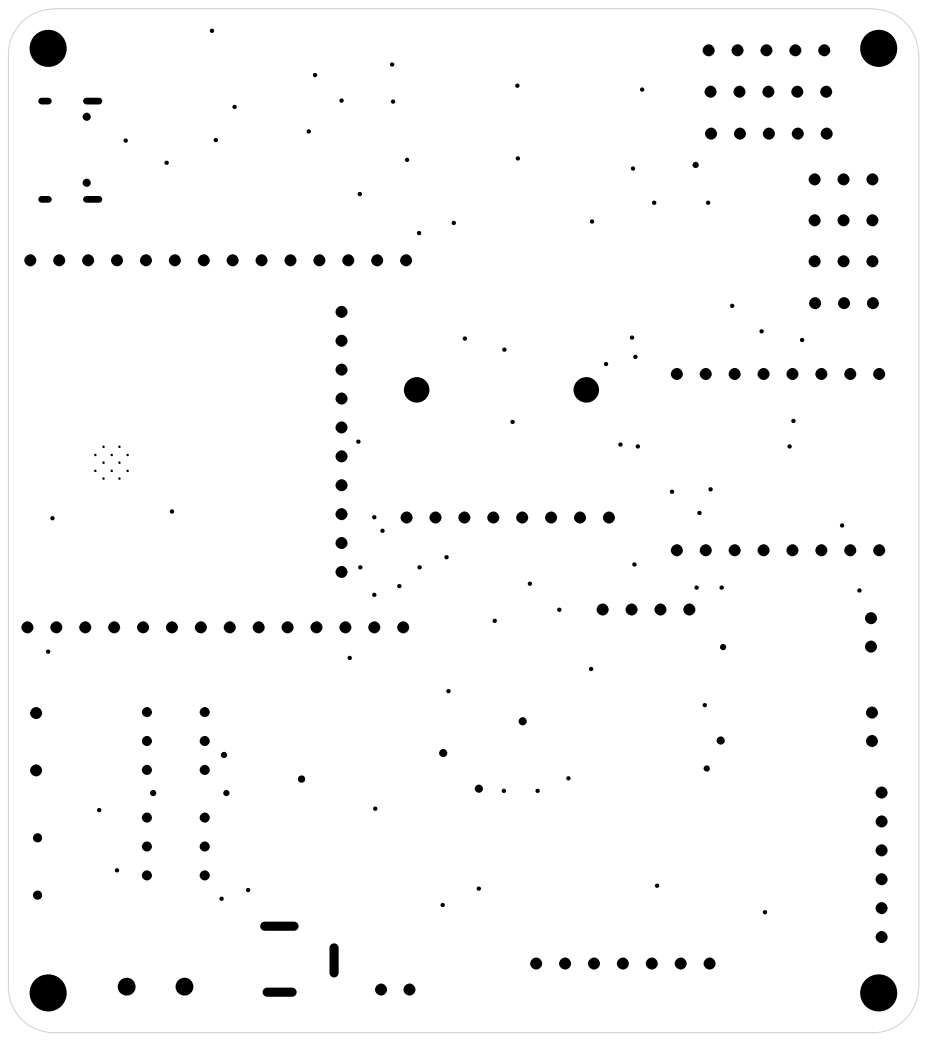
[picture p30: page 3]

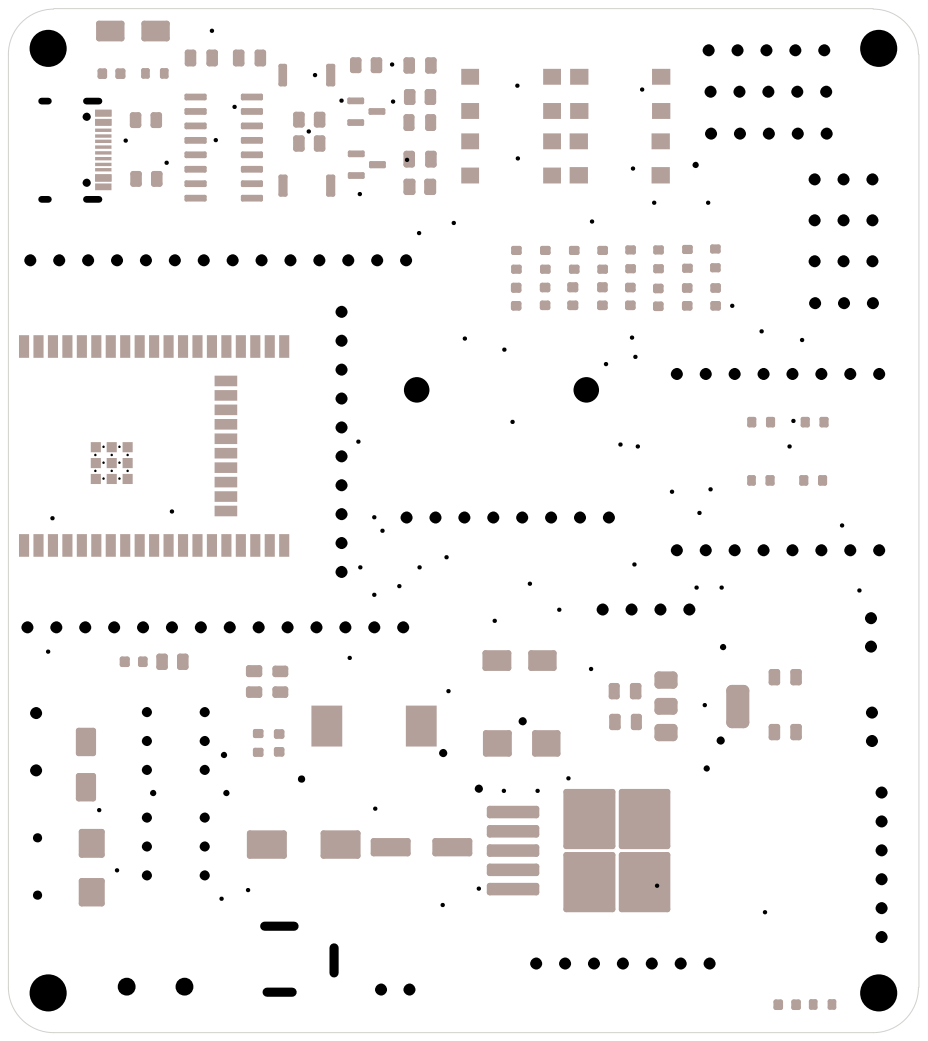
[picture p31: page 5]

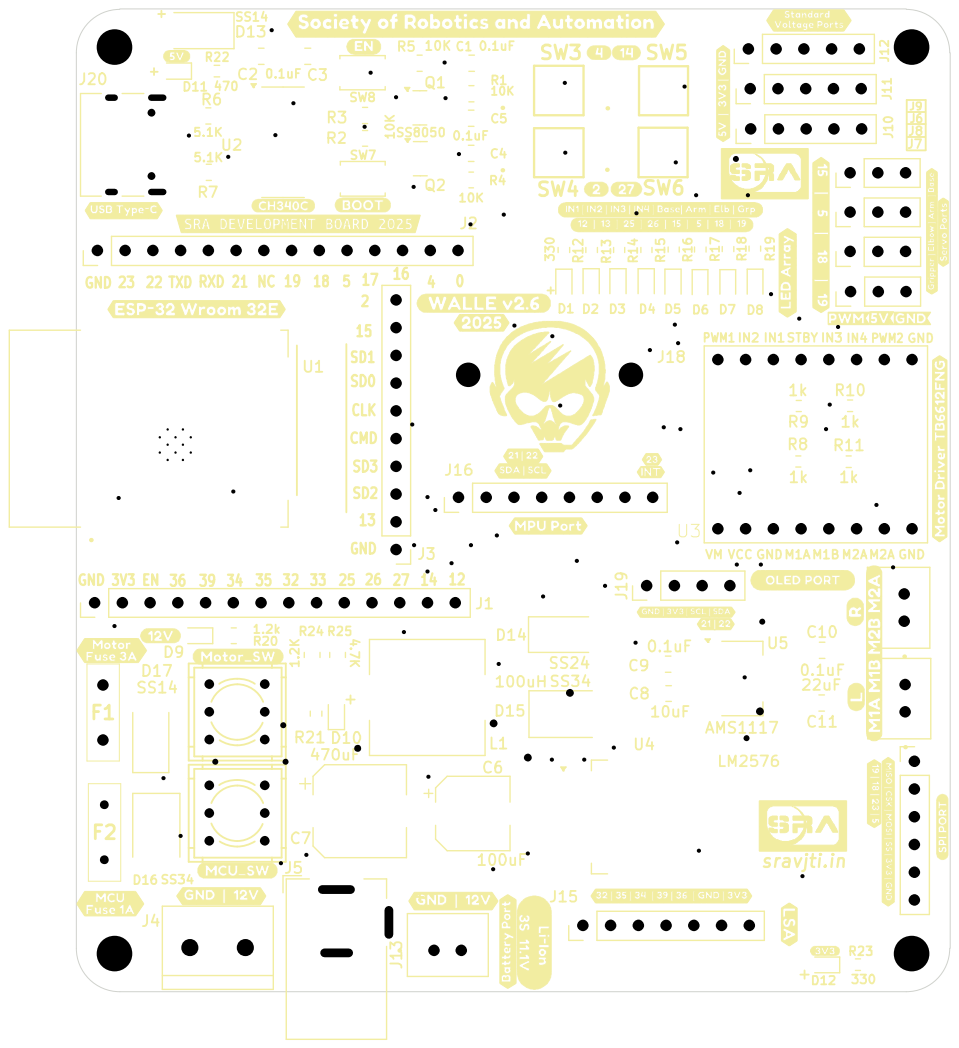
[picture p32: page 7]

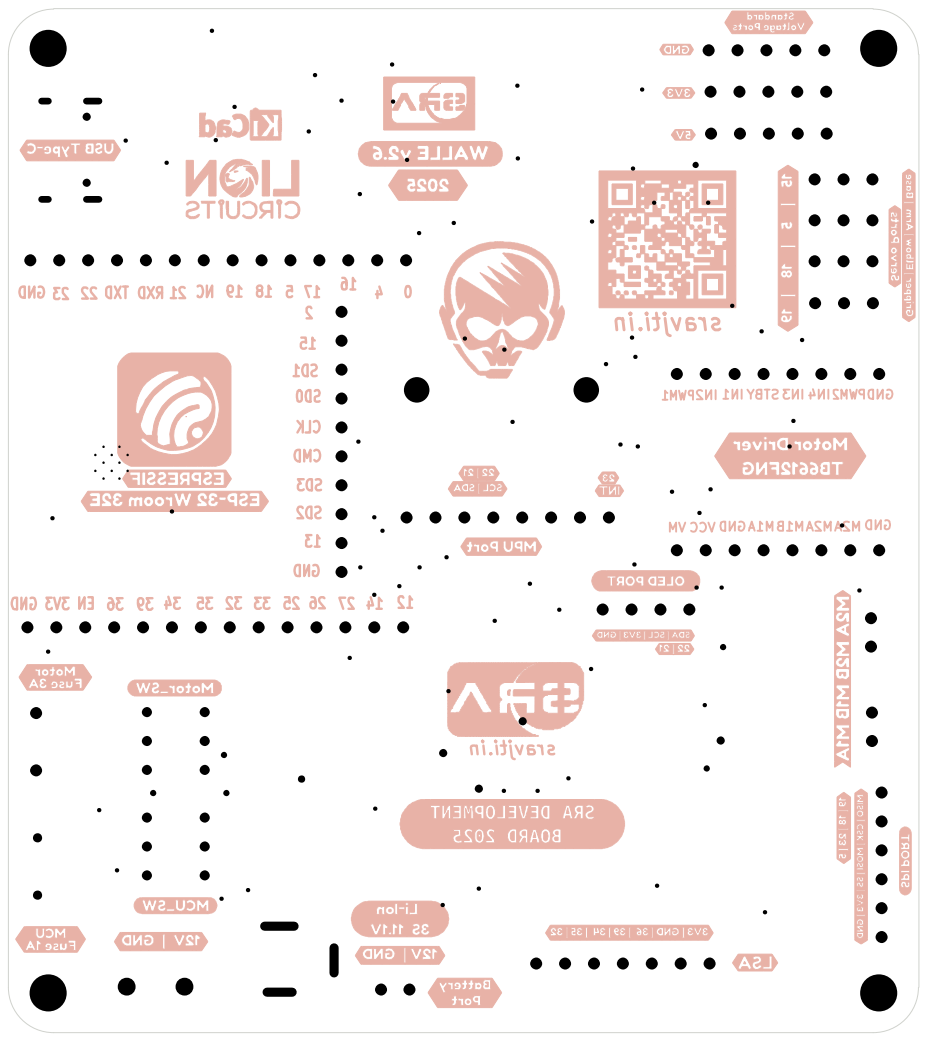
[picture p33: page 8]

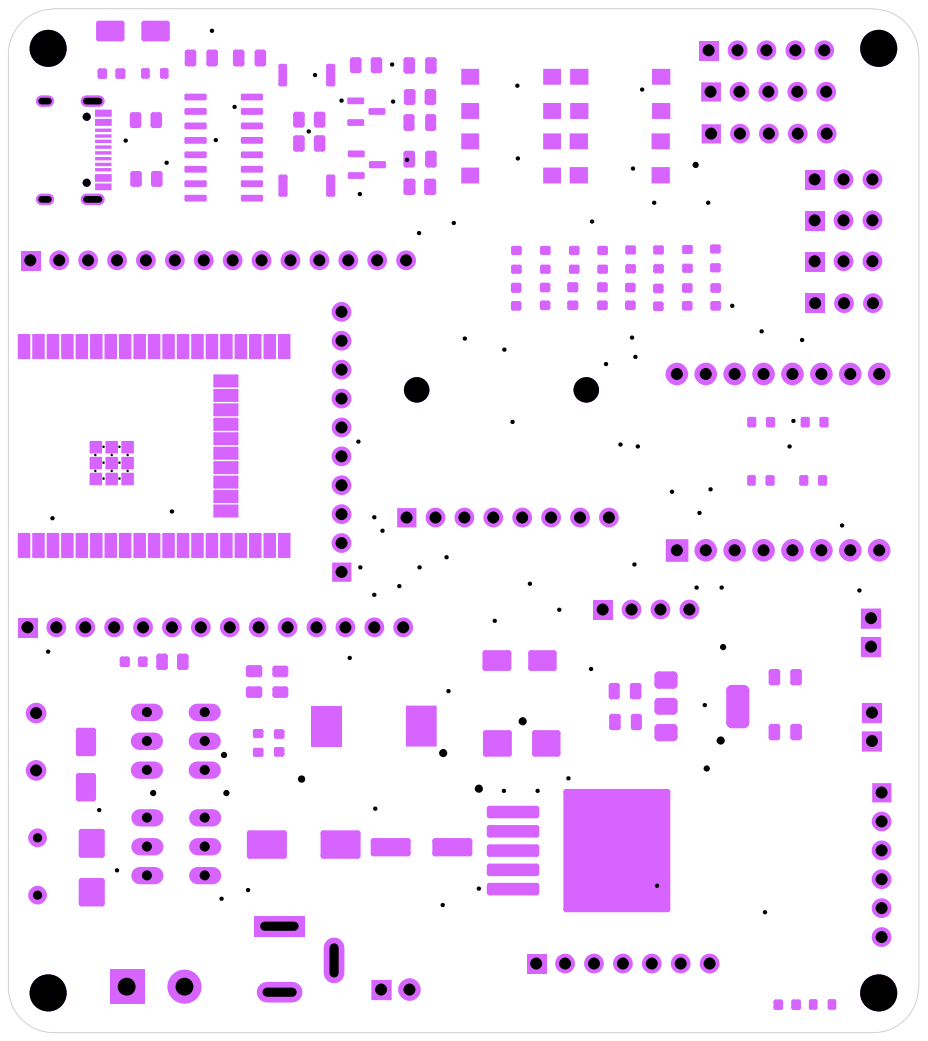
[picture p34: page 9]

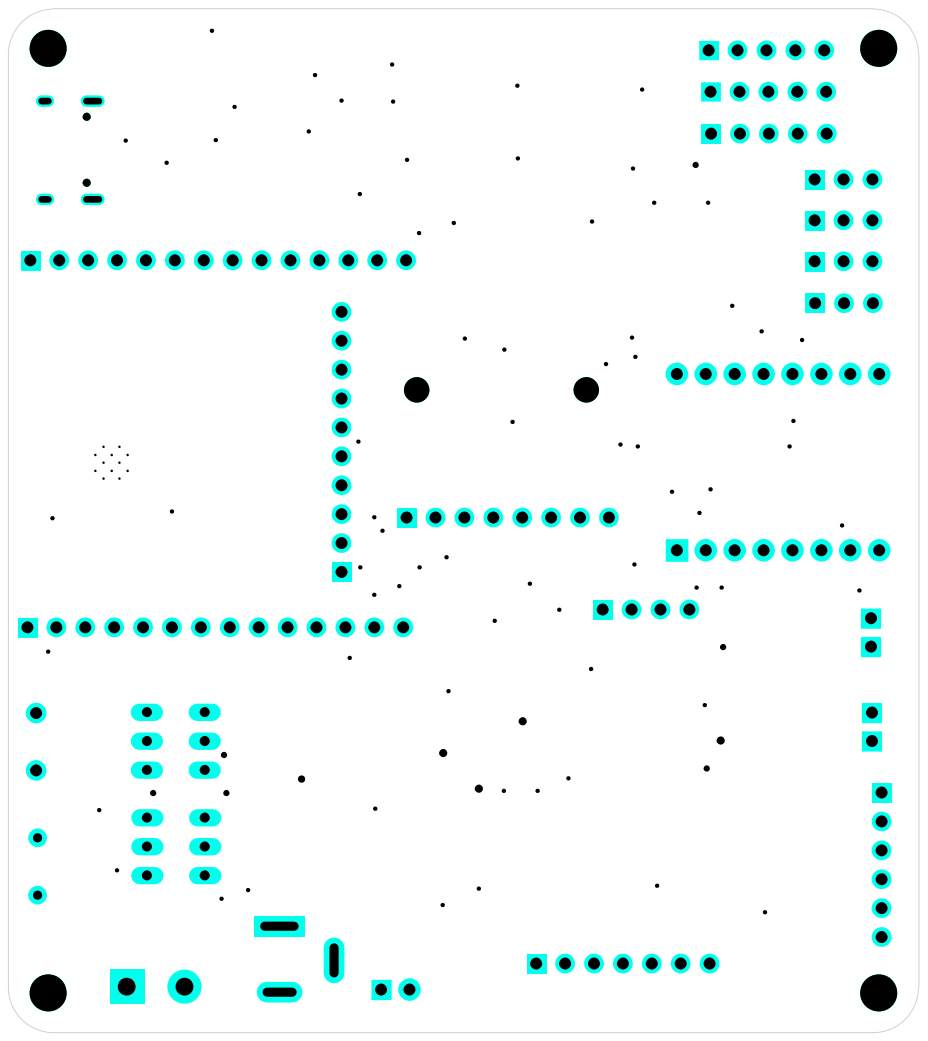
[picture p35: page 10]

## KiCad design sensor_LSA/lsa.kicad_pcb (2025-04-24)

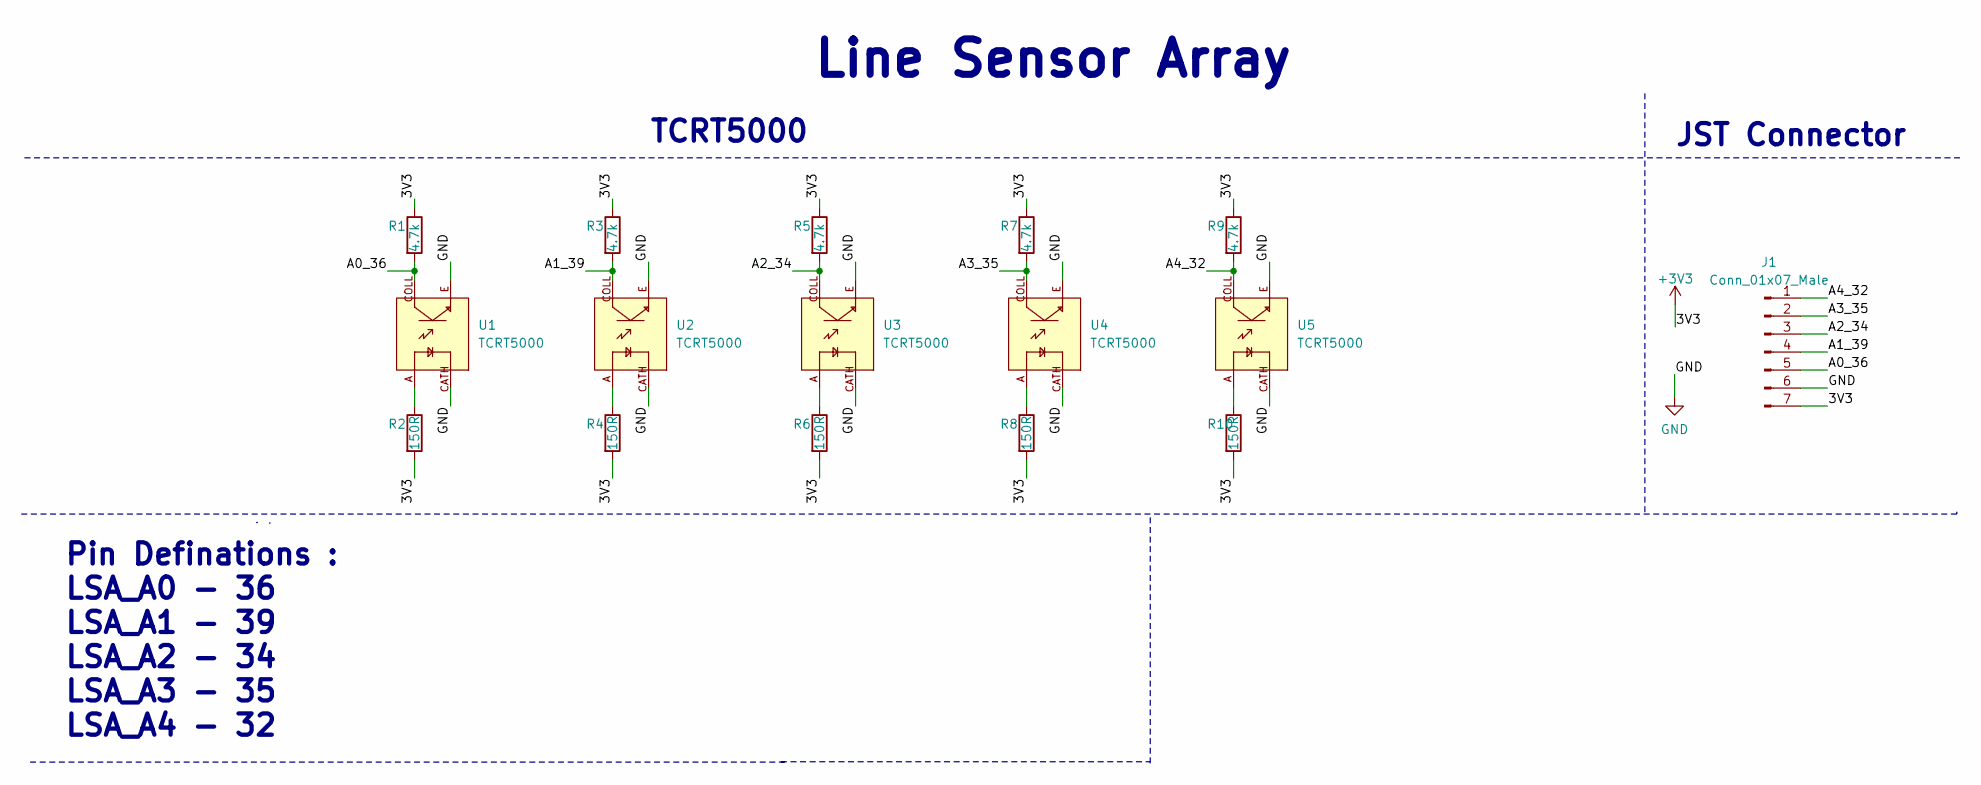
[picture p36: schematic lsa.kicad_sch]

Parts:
J1: Conn_01x07_Male; PinHeader_1x07_P2.54mm_Vertical
R1, R3, R5, R7, R9: 4.7k; R_1206_3216Metric_Pad1.30x1.75mm_HandSolder
R2, R4, R6, R8, R10: 150R; R_1206_3216Metric_Pad1.30x1.75mm_HandSolder
U1, U2, U3, U4, U5: TCRT5000; OPTO_TCRT5000; PARTREV 1.7

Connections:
+3V3: J1.7, R1.1, R2.2, R3.1, R4.2, R5.1, R6.2, R7.1, R8.2, R9.1, R10.2
/A0_36: J1.5, R1.2, U1.COLL
/A1_39: J1.4, R3.2, U2.COLL
/A2_34: J1.3, R5.2, U3.COLL
/A3_35: J1.2, R7.2, U4.COLL
/A4_32: J1.1, R9.2, U5.COLL
GND: J1.6, U1.CATH, U1.E, U2.CATH, U2.E, U3.CATH, U3.E, U4.CATH, U4.E, U5.CATH, U5.E
unnamed: R2.1, U1.A
unnamed: R4.1, U2.A
unnamed: R6.1, U3.A
unnamed: R8.1, U4.A
unnamed: R10.1, U5.A

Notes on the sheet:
JST Connector
Line Sensor Array
TCRT5000
Pin Definations : LSA_A0 - 36 LSA_A1 - 39 LSA_A2 - 34 LSA_A3 - 35 LSA_A4 - 32

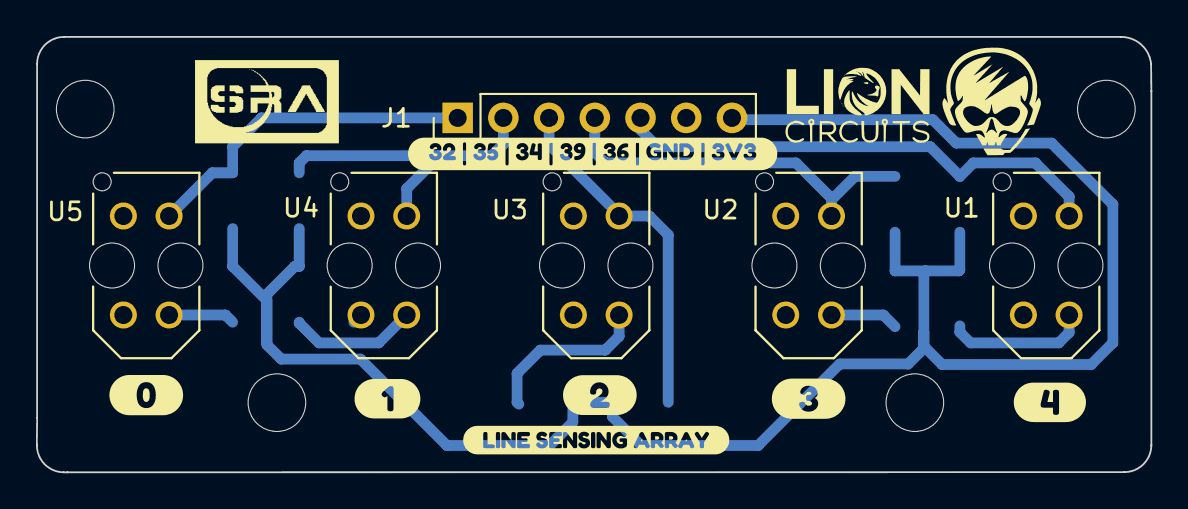
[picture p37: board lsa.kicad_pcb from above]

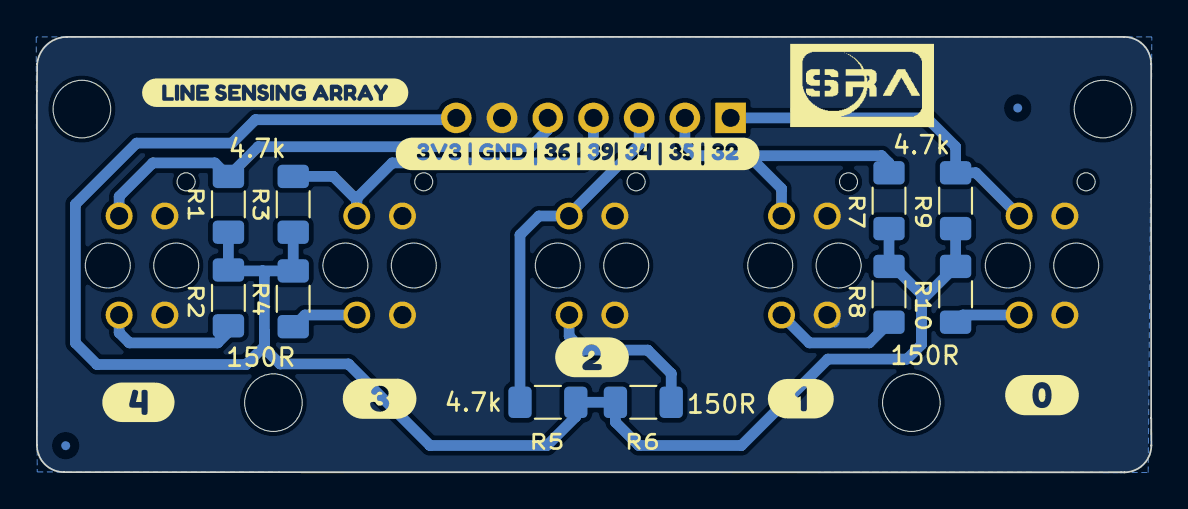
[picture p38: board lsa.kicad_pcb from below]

Board: 2 copper layers, 61.9 x 24.2 mm, 30 parts (17 on the bottom side), 12 nets.

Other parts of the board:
kibuzzard-672CF9E4, kibuzzard-672CF9E4#2: G***; kibuzzard-672CF9E4
kibuzzard-6394EC2D: G***; kibuzzard-6394EC2D
kibuzzard-63708C00: G***; kibuzzard-63708C00
kibuzzard-63708D58, kibuzzard-63708D58#2: G***; kibuzzard-63708D58
kibuzzard-63708D75, kibuzzard-63708D75#2: G***; kibuzzard-63708D75
kibuzzard-63708D85, kibuzzard-63708D85#2: G***; kibuzzard-63708D85
kibuzzard-63708DAF, kibuzzard-63708DAF#2: G***; kibuzzard-63708DAF
kibuzzard-63708DBF, kibuzzard-63708DBF#2: G***; kibuzzard-63708DBF

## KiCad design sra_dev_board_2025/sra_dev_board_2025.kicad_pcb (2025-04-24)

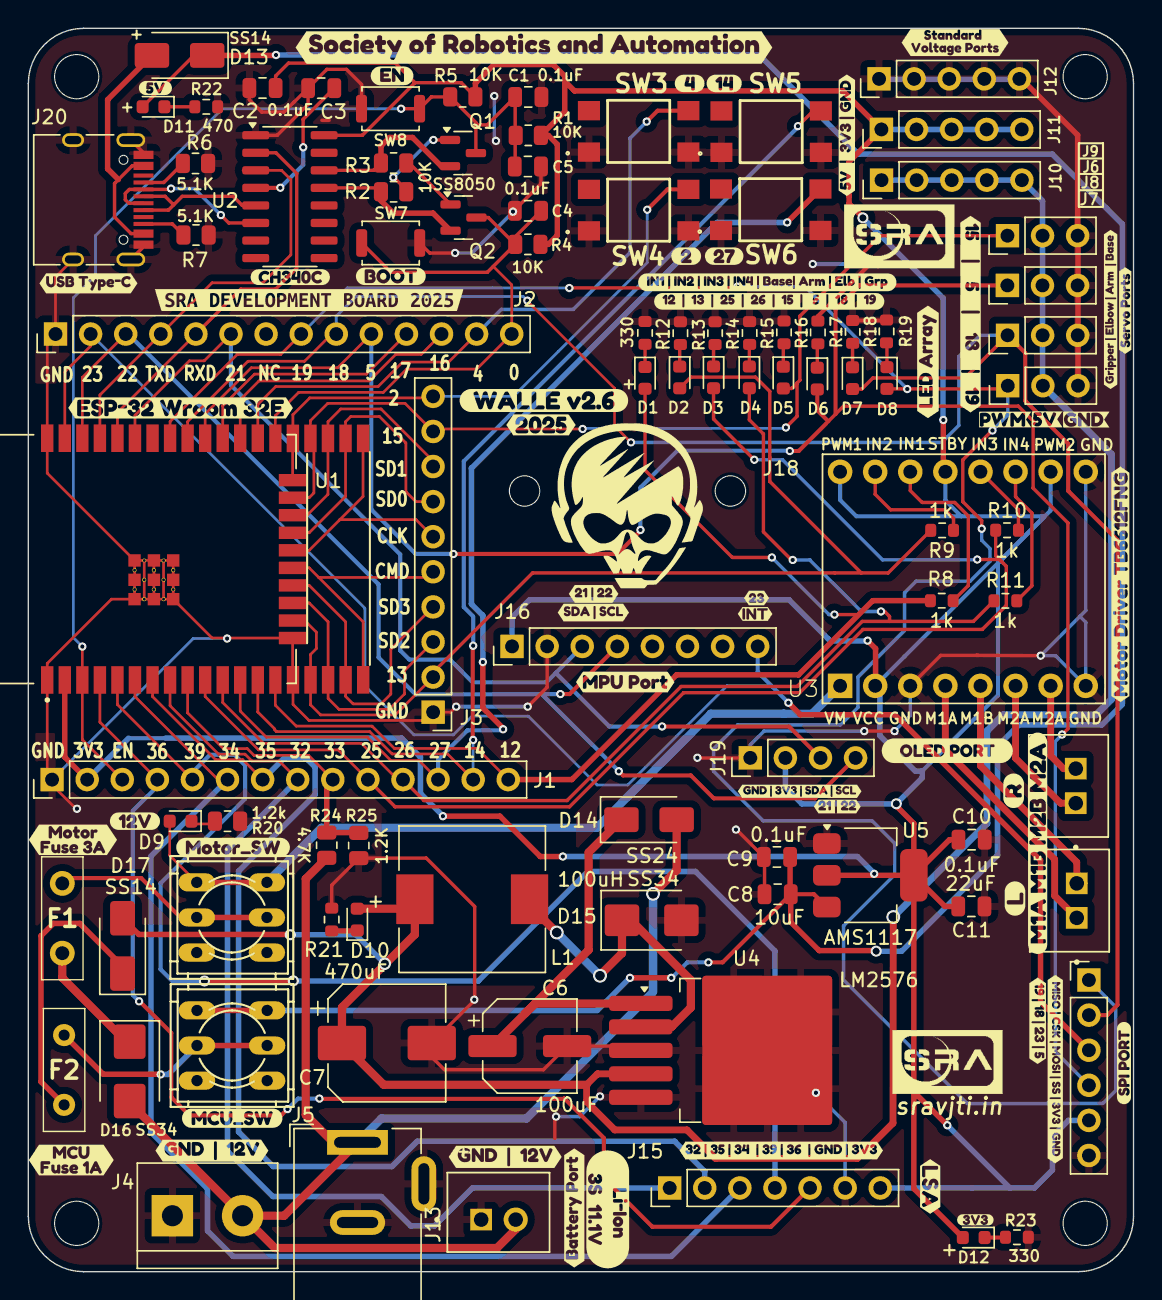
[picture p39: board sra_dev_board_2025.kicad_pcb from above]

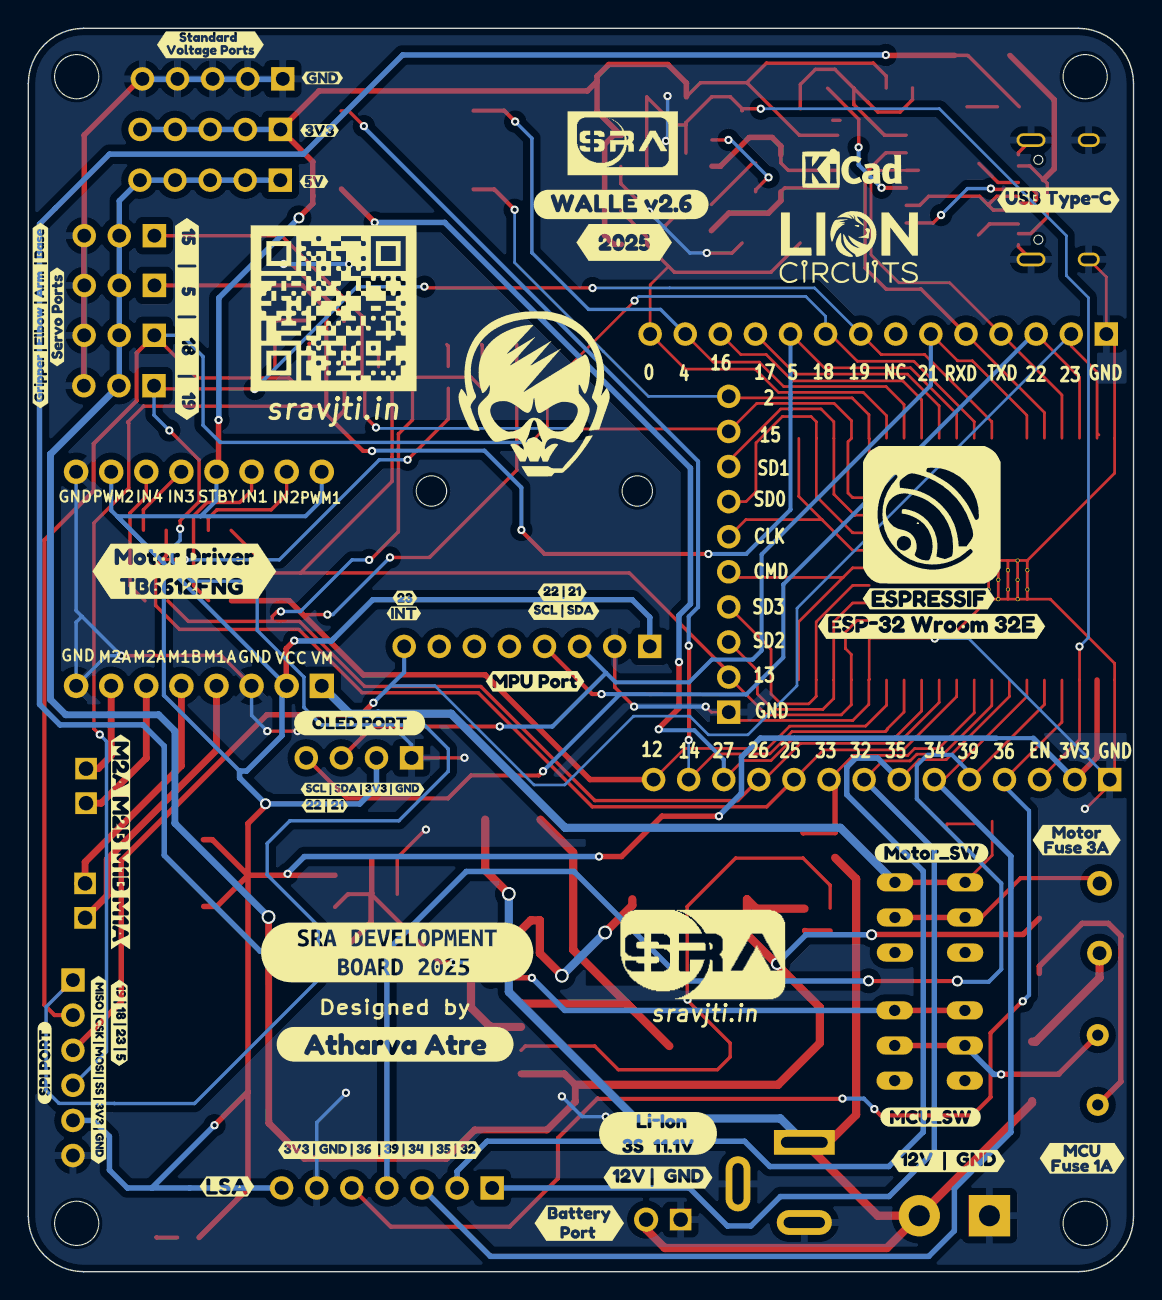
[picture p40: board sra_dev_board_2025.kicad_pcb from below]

Board: 2 copper layers, 80.0 x 90.0 mm, 184 parts (37 on the bottom side), 75 nets.

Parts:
C1, C2, C3, C4, C5, C9, C10: 0.1uF; C_0805_2012Metric
C6: 100uF; CP_Elec_6.3x7.7
C7: 470uF; CP_Elec_8x10
C8: 10uF; C_0805_2012Metric
C11: 22uF; C_0805_2012Metric
D1, D2, D3, D4, D5, D6, D7, D8, D9, D10, D11: LED; LED_0603_1608Metric
D12: +; LED_0603_1608Metric
D13, D17: SS14; D_SMA
D14: SS24; D_SMA
D15, D16: SS34; D_SMB
F1: 3A; 3A RUEF160
F2: 1A; 3A RUEF160
H1, H2, H3, H4: MountingHole; MountingHole_3.2mm_M3
J1, J2: Conn_01x14; PinHeader_1x14_P2.54mm_Vertical
J3: Conn_01x10; PinHeader_1x10_P2.54mm_Vertical
J4: Screw_Terminal_01x02; TerminalBlock_bornier-2_P5.08mm
J5: DCJ200-10-A-XX-X_REVA; BarrelJack_Wuerth_6941xx301002
J6, J7, J8, J9: Conn_01x03_Male; PinHeader_1x03_P2.54mm_Vertical
J10, J11, J12: Conn_01x05_Female; PinHeader_1x05_P2.54mm_Vertical
J13, J17, J18: B2B-XH-A_LF__SN_; 2 Pin JST Connector
J14: Conn_01x06_Female; PinHeader_1x06_P2.54mm_Vertical
J15: Conn_01x07_JST; PinHeader_1x07_P2.54mm_Vertical
J16: Conn_01x08_Female; PinHeader_1x08_P2.54mm_Vertical
J19: Conn_01x04_Female; PinHeader_1x04_P2.54mm_Vertical
J20: TYPE-C-31-M-12; USB_C_Receptacle_HRO_TYPE-C-31-M-12
L1: 100uH; L_10.4x10.4_H4.8
Q1, Q2: SS8050; SOT-23
R1, R2, R3, R4, R5: 10K; R_0805_2012Metric
R6, R7: 5.1K; R_0805_2012Metric
R8, R9, R10, R11: 1k; R_0603_1608Metric
R12, R13, R14, R15, R16, R17, R18, R19, R23: 330; R_0603_1608Metric
R20: 1.2k; R_0805_2012Metric
R21, R22: 470; R_0603_1608Metric
R24: 4.7K; R_0805_2012Metric
R25: 1.2K; R_0805_2012Metric
SW1, SW2: SW_Push_DPDT; dpdt_sw_2x03_tht
SW3, SW4, SW5, SW6: SW_Push_Dual; spst_tactile_sw_2x02_smd
SW7, SW8: SW_Push; SW_Push_SPST_NO_Alps_SKRK
U1: ESP32-WROOM-32E; ESP32-WROOM-32E__4MB_HIGH_TEMP_
U2: CH340C; SOIC-16_3.9x9.9mm_P1.27mm
U3: TB6612FNG H-bridge Motor Driver; TB6612FNG
U4: LM2576; TO-263-5_TabPin3
U5: AMS1117; SOT-223-3_TabPin2
kibuzzard-66CD8CDE: G***; kibuzzard-66CD8CDE
kibuzzard-66CD90B0, kibuzzard-66CD90B0#2: G***; kibuzzard-66CD90B0
kibuzzard-66CD901B: G***; kibuzzard-66CD901B
kibuzzard-66CDCB66: G***; kibuzzard-66CDCB66
kibuzzard-66CDD7A1, kibuzzard-66CDD7A1#2: G***; kibuzzard-66CDD7A1
kibuzzard-66CDD7D8, kibuzzard-66CDD7D8#2: G***; kibuzzard-66CDD7D8
kibuzzard-66CDD771: G***; kibuzzard-66CDD771
kibuzzard-66CDD792, kibuzzard-66CDD792#2: G***; kibuzzard-66CDD792
kibuzzard-66CF83B9, kibuzzard-66CF83B9#2: G***; kibuzzard-66CF83B9
kibuzzard-66CF86D1, kibuzzard-66CF86D1#2: G***; kibuzzard-66CF86D1
kibuzzard-66CF86E5, kibuzzard-66CF86E5#2: G***; kibuzzard-66CF86E5
kibuzzard-66CF838C, kibuzzard-66CF838C#2: G***; kibuzzard-66CF838C
kibuzzard-66D0BB59: G***; kibuzzard-66D0BB59
kibuzzard-66D06F4C: G***; kibuzzard-66D06F4C
kibuzzard-66D06F54: G***; kibuzzard-66D06F54
kibuzzard-66D06403: G***; kibuzzard-66D06403
kibuzzard-66D58886: G***; kibuzzard-66D58886
kibuzzard-67A02922: G***; kibuzzard-67A02922
kibuzzard-67BF910C: G***; kibuzzard-67BF910C
kibuzzard-67BF911E: G***; kibuzzard-67BF911E
kibuzzard-658F2C3C, kibuzzard-658F2C3C#2: G***; kibuzzard-658F2C3C
kibuzzard-658F2C13, kibuzzard-658F2C13#2: G***; kibuzzard-658F2C13
kibuzzard-668D4F46, kibuzzard-668D4F46#2: G***; kibuzzard-668D4F46
kibuzzard-668D4F81, kibuzzard-668D4F81#2: G***; kibuzzard-668D4F81
kibuzzard-668D5592: G***; kibuzzard-668D5592
kibuzzard-668D6178: G***; kibuzzard-668D6178
kibuzzard-668FE423: G***; kibuzzard-668FE423
kibuzzard-668FF9B2, kibuzzard-668FF9B2#2: G***; kibuzzard-668FF9B2
kibuzzard-675FD791: G***; kibuzzard-675FD791
kibuzzard-675FDA6A: G***; kibuzzard-675FDA6A
kibuzzard-675FDACE: G***; kibuzzard-675FDACE
kibuzzard-675FDAD6: G***; kibuzzard-675FDAD6
kibuzzard-675FDAE3: G***; kibuzzard-675FDAE3
kibuzzard-675FDAEB: G***; kibuzzard-675FDAEB
kibuzzard-675FDD5C: G***; kibuzzard-675FDD5C
kibuzzard-675FDE17: G***; kibuzzard-675FDE17
kibuzzard-675FE5A8: G***; kibuzzard-675FE5A8
kibuzzard-675FE5B2: G***; kibuzzard-675FE5B2
kibuzzard-675FEDA3: G***; kibuzzard-675FEDA3
kibuzzard-675FF2F7: G***; kibuzzard-675FF2F7
kibuzzard-675FF2FE, kibuzzard-675FF2FE#2: G***; kibuzzard-675FF2FE
kibuzzard-675FF39E: G***; kibuzzard-675FF39E
kibuzzard-675FF567: G***; kibuzzard-675FF567
kibuzzard-675FF648: G***; kibuzzard-675FF648
kibuzzard-6774F3BB: G***; kibuzzard-6774F3BB
kibuzzard-6774F4AA: G***; kibuzzard-6774F4AA
kibuzzard-6774F4AE: G***; kibuzzard-6774F4AE
kibuzzard-6774F51E: G***; kibuzzard-6774F51E
kibuzzard-66914CE9: G***; kibuzzard-66914CE9
kibuzzard-67602BF7: G***; kibuzzard-67602BF7
kibuzzard-67602C07: G***; kibuzzard-67602C07
kibuzzard-67602C35: G***; kibuzzard-67602C35
kibuzzard-67602C64: G***; kibuzzard-67602C64
kibuzzard-67602CD0: G***; kibuzzard-67602CD0
kibuzzard-67602CEF: G***; kibuzzard-67602CEF
kibuzzard-67602E60: G***; kibuzzard-67602E60
kibuzzard-67602E69: G***; kibuzzard-67602E69
kibuzzard-67602EA4: G***; kibuzzard-67602EA4
kibuzzard-67704BF1: G***; kibuzzard-67704BF1
kibuzzard-67704C04: G***; kibuzzard-67704C04
kibuzzard-67704CCE: G***; kibuzzard-67704CCE
kibuzzard-67704CDF: G***; kibuzzard-67704CDF
kibuzzard-67704CF4: G***; kibuzzard-67704CF4
kibuzzard-67704D9C: G***; kibuzzard-67704D9C
kibuzzard-67704D11: G***; kibuzzard-67704D11
kibuzzard-67704D22: G***; kibuzzard-67704D22
kibuzzard-67715A02: G***; kibuzzard-67715A02
kibuzzard-67715A46: G***; kibuzzard-67715A46
kibuzzard-669207B4: G***; kibuzzard-669207B4
kibuzzard-677158DD: G***; kibuzzard-677158DD
kibuzzard-6692092C: G***; kibuzzard-6692092C
kibuzzard-66920921: G***; kibuzzard-66920921
kibuzzard-66920939: G***; kibuzzard-66920939
kibuzzard-66921043: G***; kibuzzard-66921043
kibuzzard-66923428: G***; kibuzzard-66923428

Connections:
/0: C4.2, J2.14, Q2.3, R4.1, SW7.2, U1.25 (IO0)
/2: J3.10, SW4.4, U1.24 (IO2)
/3V3: C2.1, C10.1, C11.1, D12.2 (A), J1.2, J11.1, J11.2, J11.3, J11.4, J11.5, J14.5, J15.7, J16.1, J19.2, R1.2, R4.2, R5.2, U1.2 (VDD), U2.16 (VCC), U3.2 (VCC), U3.10 (PWMB), U3.13 (STBY), U3.16 (PWMA), U5.2 (VO)
/4: J2.13, SW3.4, U1.26 (IO4)
/5: D6.2 (A), J2.10, J6.1, J14.4, U1.29 (IO5)
/5V: C7.1, D10.2 (A), D17.2 (A), J6.2, J7.2, J8.2, J9.2, J10.1, J10.2, J10.3, J10.4, J10.5, L1.2, U4.4 (FB)
/5V_P: C8.1, C9.1, D11.2 (A), D13.1 (K), SW2.3 (C), SW2.6 (C), U5.3 (VI)
/12: D1.2 (A), J1.14, R8.1, U1.14 (IO12)
/12V: D14.2 (A), D16.2 (A), J4.2, J5.1, J13.2, R24.1
/12V_P: D9.2 (A), SW1.3 (C), SW1.6 (C), U3.1 (VM)
/13: D2.2 (A), J3.2, R9.1, U1.16 (IO13)
/14: J1.13, SW5.4, U1.13 (IO14)
/15: D5.2 (A), J3.9, J9.1, U1.23 (IO15)
/16: J2.12, U1.27 (IO16)
/17: J2.11, U1.28 (IO17)
/18: D7.2 (A), J2.9, J8.1, J14.2, U1.30 (IO18)
/19: D8.2 (A), J2.8, J7.1, J14.1, U1.31 (IO19)
/21: J2.6, J16.3, J19.3, U1.33 (IO21)
/22: J2.3, J16.4, J19.4, U1.36 (IO22)
/23: J2.2, J14.3, J16.8, U1.37 (IO23)
/25: D3.2 (A), J1.10, R10.1, U1.10 (IO25)
/26: D4.2 (A), J1.11, R11.1, U1.11 (IO26)
/27: J1.12, SW6.4, U1.12 (IO27)
/32: J1.8, J15.1, U1.8 (IO32)
/33: J1.9, R24.2, R25.2, U1.9 (IO33)
/34: J1.6, J15.3, U1.6 (IO34)
/35: J1.7, J15.2, U1.7 (IO35)
/36: J1.4, J15.5, U1.4 (SENSOR_VP)
/39: J1.5, J15.4, U1.5 (SENSOR_VN)
/CC1: J20.A5 (CC1), R6.1
/CC2: J20.B5 (CC2), R7.1
/CLK: J3.6, U1.20 (NC)
/CMD: J3.5, U1.19 (NC)
/DN1: J20.A7 (DN1), J20.B7 (DN2), U2.6 (UD-)
/DP1: J20.A6 (DP1), J20.B6 (DP2), U2.5 (UD+)
/EN: C1.1, C5.2, J1.3, Q1.3, R1.1, R5.1, SW8.2, U1.3 (EN)
/M1A: J17.1, U3.4 (A01)
/M1B: J17.2, U3.5 (A02)
/M2A: J18.2, U3.7 (B01)
/M2B: J18.1, U3.6 (B02)
/RXD: J2.5, U1.34 (RXD0/IO3), U2.2 (TXD)
/SD0: J3.7, U1.21 (NC)
/SD1: J3.8, U1.22 (NC)
/SD2: J3.3, U1.17 (NC)
/SD3: J3.4, U1.18 (NC)
/TXD: J2.4, U1.35 (TXD0/IO1), U2.3 (RXD)
/VBUSC: D13.2 (A), J20.A4, J20.A9, J20.B4, J20.B9
/~DTR: Q2.2, R2.1, U2.13 (~DTR)
/~RTS: Q1.2, R3.1, U2.14 (~RTS)
GND: C1.2, C2.2, C3.2, C4.1, C5.1, C6.2, C7.2, C8.2, C9.2, C10.2, C11.2, D15.2 (A), J1.1, J2.1, J3.1, J4.1, J5.2, J5.3, J6.3, J7.3, J8.3, J9.3, J12.1, J12.2, J12.3, J12.4, J12.5, J13.1, J14.6, J15.6, J16.2, J19.1, J20.A1, J20.A12, J20.B1, J20.B12, J20.S1 (SHIELD), R6.2, R7.2, R12.2, R13.2, R14.2, R15.2, R16.2, R17.2, R18.2, R19.2, R20.2, R21.2, R22.2, R23.2, R25.1, SW3.1, SW3.2, SW4.1, SW4.2, SW5.1, SW5.2, SW6.1, SW6.2, SW7.1, SW8.1, U1.1 (GND), U1.15 (GND), U1.38 (GND), U1.39_1, U1.39_2, U1.39_3, U1.39_4, U1.39_5, U1.39_6, U1.39_7, U1.39_8, U1.39_9, U1.39_10, U1.39_11, U1.39_12, U1.39_13, U1.39_14, U1.39_15, U1.39_16, U1.39_17, U1.39_18, U1.39_19, U1.39_20, U1.39_21, U2.1 (GND), U3.3 (GND), U3.8 (GND), U3.9 (GND), U4.3 (GND), U4.5 (~ON/OFF), U5.1 (GND)
unnamed: D1.1 (K), R12.1
unnamed: D2.1 (K), R13.1
unnamed: D3.1 (K), R14.1
unnamed: D4.1 (K), R15.1
unnamed: D5.1 (K), R16.1
unnamed: D6.1 (K), R17.1
unnamed: D7.1 (K), R18.1
unnamed: D8.1 (K), R19.1
unnamed: D9.1 (K), R20.1
unnamed: D10.1 (K), R21.1
unnamed: D11.1 (K), R22.1
unnamed: D12.1 (K), R23.1
unnamed: C6.1, D14.1 (K), U4.1 (VIN)
unnamed: D15.1 (K), L1.1, U4.2 (OUT)
unnamed: D16.1 (K), F1.1
unnamed: D17.1 (K), F2.1
unnamed: F1.2, SW1.2 (B), SW1.5 (B)
unnamed: F2.2, SW2.2 (B), SW2.5 (B)
unnamed: Q1.1, R2.2
unnamed: Q2.1, R3.2
unnamed: C3.1, U2.4 (V3)
unnamed: R8.2, U3.14 (AI1)
unnamed: R9.2, U3.15 (AI2)
unnamed: R10.2, U3.12 (BI1)
unnamed: R11.2, U3.11 (BI2)

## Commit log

2025-04-24 Update PCB files for 2025 Board (#29)
    * PCB Files update for 2025
    * Add contributors in the README.md file
    ---------
    [12V_1x02_tht.step, 1N5822.STEP, A4988_STEPPER_MOTOR_DRIVER_CARRIER.step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]
2025-06-25 updated assets and readme for 2025 board
2025-06-25 Revert "Updated Readme and assets for SRA board 2024-25" (#31)
2025-06-25 sensors_LSA: Update the LSA images according to the 2025 board (#32)
